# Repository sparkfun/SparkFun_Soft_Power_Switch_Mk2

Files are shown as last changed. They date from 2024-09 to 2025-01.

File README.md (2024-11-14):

SparkFun Soft Power Switch - JST 2mm
===================================================

SparkFun Soft Power Switch - JST 2mm (PRT-26993) (https://www.sparkfun.com/products/26993)

[*SparkFun Soft Power Switch - JST 2mm (PRT-26993)*](https://www.sparkfun.com/products/26993)

The Soft Power Switch - JST 2mm is a passive, hard on/off switch with software feedback and control. In other words, it's like the on/off switch on a laptop. A simple press will turn the system on. Another press can (with MCU intervention) turn off the system. And if things go really wrong, pressing and holding the button for ~7 seconds will force a power-down. If you're building something with an enclosed battery and need a good power button, this is the board you need.

The [Mk1 Soft Power Switch](https://www.sparkfun.com/products/17870) is great, but we do see occasional issues caused by component tolerances or the operating temperature. Mk2 is based on an application note by Texas Instruments, and is a completely digital design. It is based around a 74LVC1G175 D-type flip-flop - remember those?! - and is insensitive to temperature and component variation. It also includes improvements like: an over-current self-resetting 2A fuse; input and output LEDs. This version has JST 2mm battery connectors.

The PUSH pin can act as an output to a microcontroller indicating the state of the power button (high = not pressed, low = user is pressing power button). This can be used as an input to your firmware to begin to shut down before power is lost. PUSH is an open-drain output and requires a pull-up. Alternatively, the OFF pin can be driven **high** by the system forcing fast power off via software. (For Mk1, the Fast Off pin was driven **low**.)

The most common use case is something like this:

* Microcontroller begins running code and checks to see if the power button is still being pressed for X milliseconds.
* If not, it's just a tap, go back to sleep.
* If yes, power up and run normal program.

Later...

* User presses power button in normal program
* If power button is pressed for <X milliseconds, it's just a tap, ignore.
* If power button is pressed for >X milliseconds, it's time to power down.

The wake-up and power-down times can be tweaked for your own user experience but we found 500ms for power up and 2s for power down work really well.

If needed, pads are provided for a larger, external button.

The Soft Power Switch supports battery charging. If the target device has onboard LiPo charging, current can be passed back through the switch circuit and charge the battery.

<b>Heads up!</b> The Soft Power Switch - JST 2mm works up to 5.5V only. (Mk1 is good up to 12V.)

Pros:

* Very low µA quiescent current
* Hard override power down in case your microcontroller loses its mind
* PUSH and OFF pins can be connected to a microcontroller
* Supports battery charging

Cons:

* Limited to 2A continuous, 4A peak (fuse protected)
* No AC loads

Features
-------------------
* Input voltage: 5.5V maximum, 1.8V minimum
    * Typically ~3.7V from a single cell LiPo Battery
* Maximum current draw: 2A continuous, 4A peak (fuse protected)
* SIL2308 N&P-Channel MOSFET
    * 70mΩ (0.070 Ohm) typical P-Channel on-resistance
* Very low quiescent current: <1µA @ 3.75V, with VIN LED disabled
* 2x 2-Pin JST Right-Angle Connectors
    * VIN
    * VOUT
* Supports battery charging
* Built-in momentary push button
  * Hard override: push and hold the button for ~10 seconds
* Breakout PTH:
  * GND, VIN, VOUT
  * BTN: if desired, connect an external button between BTN and GND
  * PUSH: open-drain output, requires pull-up, low indicates button is pushed
  * OFF: drive high to turn the output off
* LEDs: VIN and VOUT (can be disabled if desired)
* Jumpers
  * Input power LED
  * Output power LED
* Dimensions: 1.0in. x 1.0in. (25.4mm x 25.4mm)
* Weight: 3.10g

Repository Contents
-------------------

* **.github/workflows** - YAML files used for GitHub Actions and GitHub Pages/mkdocs
* **/Examples** - Example sketches demonstrating how to read and control the switch
* **/Hardware** - KiCad design files (kicad_pro, .kicad_pcb, .kicad_sch)
  * **/Production** - Production panel files
* **/docs** - Online documentation files
  * **/assets** - Folder containing all the file assets used for product documentation
    *  **/3d_model** - Exported 3D models from KiCad
    * **/board_files** - Copy of design files used for product documentation
    * **/component_documentation** - Datasheets and manuals for hardware components
    * **/img** - Images for product documentation
  * **/github** - Files stating how to contribute and filing issues used for product documentation
  * **/javascript** - Folder containing custom javascript used for product documentation
  * **/stylesheet** - Folder containing CSS files used for product documentation
* **/overrides** - Customization files used for product documentation
  * **/.icons** - Icons used for GitHub used for product documentation
  * **./partials** - Used for product documentation
* **LICENSE.md** contains the license information

Documentation
--------------
* **[Hookup Guide](https://docs.sparkfun.com/SparkFun_Soft_Power_Switch_Mk2)** - Basic hookup guide for the Soft Power Switch - JST 2mm.

Product Versions
----------------
* [PRT-26993](https://www.sparkfun.com/products/26993) - SparkFun Red Release Soft Power Switch - JST 2mm
* [SPX-25365](https://www.sparkfun.com/products/25365) - Original SparkX Release Soft Power Switch Mk2 - JST 2mm
* [SPX-17870](https://www.sparkfun.com/products/17870) - Original SparkX Release Mk1

Version History
---------------
* v1.0 - SparkFun Soft Power Switch - JST 2mm (PRT-26993)
* v01 - Original SparkX Soft Power Switch MK2 - JST 2mm (SPX-25365)
* v1.0 - Original SparkX Soft Power Switch Mk1 (SPX-17870)

License Information
-------------------

This product is _**open source**_!

Please review the LICENSE.md file for license information.

If you have any questions or concerns on licensing, please contact technical support on our [SparkFun forums](https://forum.sparkfun.com/viewforum.php?f=123).

Distributed as-is; no warranty is given.

- Your friends at SparkFun.

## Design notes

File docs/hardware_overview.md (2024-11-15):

In this section, we will highlight the hardware and pins that are broken out on the SparkFun Soft Power Switch - JST 2mm. For more information, check out our [Resources and Going Further](../resources/) on the components used on the breakout board.

<div style="text-align: center;">
  <table>
    <tr style="vertical-align:middle;">
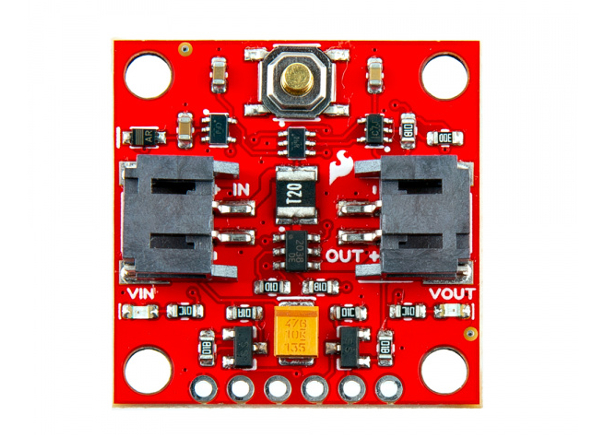
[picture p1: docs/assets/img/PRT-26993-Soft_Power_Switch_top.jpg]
Top View
     <td style="text-align: center; vertical-align: middle; border: solid 1px #cccccc;"></td>
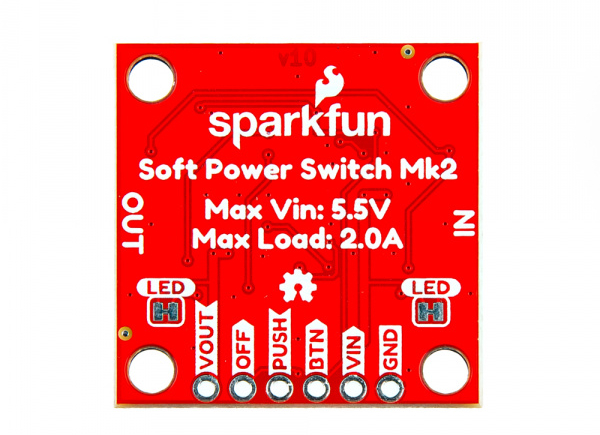
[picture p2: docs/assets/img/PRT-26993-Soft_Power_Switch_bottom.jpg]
Bottom View
     <td style="text-align: center; vertical-align: middle; border: solid 1px #cccccc;"></td>
    </tr>
    <tr style="vertical-align:middle;">
     <td style="text-align: center; vertical-align: middle; border: solid 1px #cccccc;"><i>Top View</i></td>
     <td style="text-align: center; vertical-align: middle; border: solid 1px #cccccc;"><i>Bottom View</i></td>
    </tr>
  </table>
</div>

### Soft Power Switch Versions

The [SparkX Mk1 Soft Power Switch](https://www.sparkfun.com/products/17870) is great, but we do see occasional issues caused by component tolerances or the operating temperature. Mk2 is based on an application note by Texas Instruments, and is a completely digital design. It is based around a 74LVC1G175 D-type flip-flop - remember those?! - and is insensitive to temperature and component variation.

<div style="text-align: center;">
  <table>
    <tr style="vertical-align:middle;">
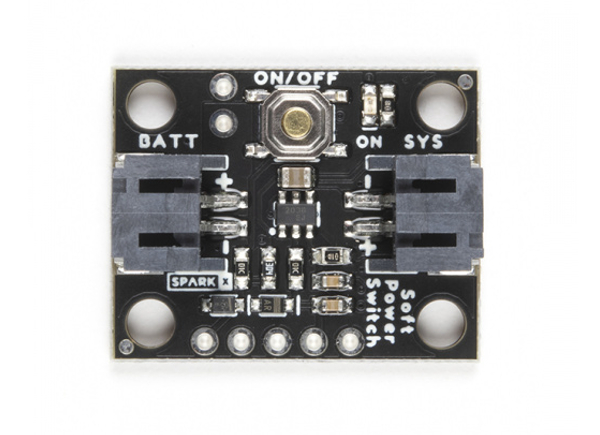
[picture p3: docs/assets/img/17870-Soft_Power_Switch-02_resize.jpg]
SparkX Soft Power Switch Mk1
     <td style="text-align: center; vertical-align: middle; border: solid 1px #cccccc;"></td>
     <td style="text-align: center; vertical-align: middle; border: solid 1px #cccccc;"><a href="../assets/img/PRT-26993-Soft_Power_Switch_top.jpg">SparkFun Soft Power Switch - JST 2mm</a></td>
    </tr>
    <tr style="vertical-align:middle;">
     <td style="text-align: center; vertical-align: middle; border: solid 1px #cccccc;"><i>SparkX Soft Power Switch Mk1</i></td>
     <td style="text-align: center; vertical-align: middle; border: solid 1px #cccccc;"><i>SparkFun Soft Power Switch - JST 2mm</i></td>
    </tr>
  </table>
</div>

It also includes improvements like:

- An over-current self-resetting 2A fuse.
- Input and output LEDs.
- LED jumpers.
- Improved momentary button (i.e. the height of the button is increased).

Differences include:

- The Soft Power Switch - JST 2mm works up to 5.5V only (the Mk1 is good up to 12V).
- For Mk2, driving the fast OFF pin HIGH by the system will force fast power off via software. However for Mk1, the fast OFF pin was driven low.
- Slightly bigger PCB: 1.0"x1.0" sized breakout (the Mk1 was 0.8"x1.0").

### Power

!!! warning
    The Soft Power Switch - JST 2mm works up to 5.5V only. (Mk1 is good up to 12V.)

!!! warning
    The Soft Power Switch - JST 2mm was designed to work with DC loads. Unfortunately, the board is not designed for AC loads.

!!! note
    Once the Soft Power Switch - JST 2mm is powered, it will take a few seconds to discharge power after disconnecting the power source from the IN port. So if you decide to do quick power cycle, the board can still be powered if there is not a long enough delay.

The maximum input voltage that the Soft Power Switch - JST 2mm can handle is **5.5V** while the minimum input voltage is _1.8V_. The board was designed to be used with single cell LiPo batteries with the built-in 2-pin JST connector, so the typical voltage will be about 3.7V nominally. The maximum current draw that the board can handle is 2A continuous and 4A peak (fuse protected). With the VIN LED disabled, the board has a very low quiescent current: <1&micro;A @ 3.75V.

* **VIN** &mdash; This pin is the voltage input. As stated above, the maximum input voltage is 5.5V while the minimum is 1.8V. Voltage is applied to this pin from a single cell LiPo battery which is about 3.7V nominally.
* **VOUT** &mdash; The output voltage of the board whenever the switch is active.
* **GND** &mdash; Of course, is the common, ground voltage (0V reference) for the system.

<div style="text-align: center;">
  <table>
    <tr style="vertical-align:middle;">
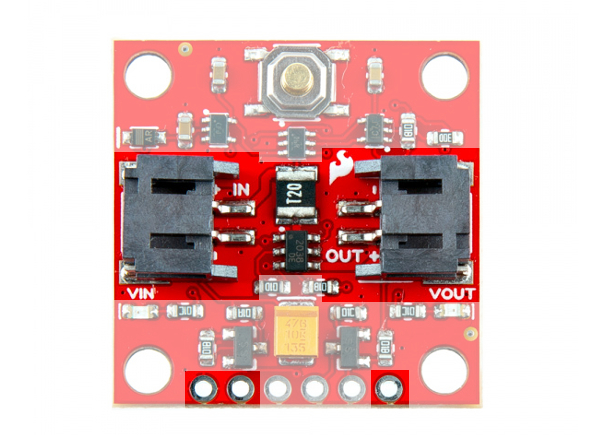
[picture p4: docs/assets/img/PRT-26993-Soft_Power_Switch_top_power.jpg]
Power, Ground and JST Connectors, Top View
     <td style="text-align: center; vertical-align: middle; border: solid 1px #cccccc;"></td>
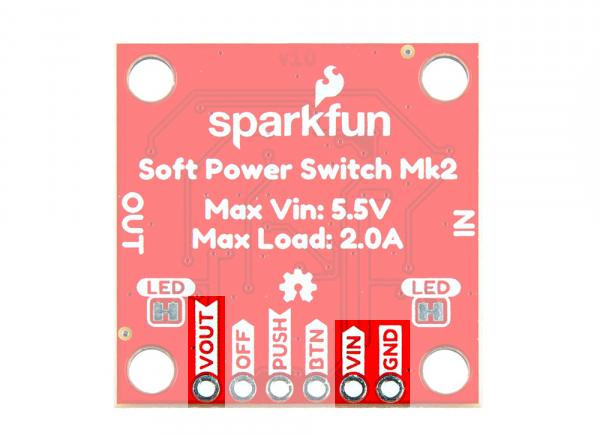
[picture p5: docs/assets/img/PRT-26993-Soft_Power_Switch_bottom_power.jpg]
Power, Ground and JST Connectors Highlighted, Bottom View
     <td style="text-align: center; vertical-align: middle; border: solid 1px #cccccc;"></td>
    </tr>
    <tr style="vertical-align:middle;">
     <td style="text-align: center; vertical-align: middle; border: solid 1px #cccccc;" colspan="2"><i>Power, Ground and JST Connectors Highlighted</i></td>
    </tr>
  </table>
</div>

The Soft Power Switch - JST 2mm also supports battery charging. If the target device has onboard LiPo charging, current can be passed back through the switch circuit and charge the battery.

### Power Button and Button State

The board includes a built-in momentary push button as the power button. This pin is broken out to a PTH for users to connect an external button. There is also the PUSH pin to indicate the button's state. The PUSH pin can act as an output to a microcontroller indicating the state of the power button (HIGH = not pressed, LOW = user is pressing power button). This can be used as an input to your firmware to begin to shut down before power is lost. Alternatively, there is also an OFF pin that can be driven HIGH by the system forcing fast power off via software. Below is a summary of the pins broken out.

* **BTN** &mdash; Short for button. If desired, connect this input pin to an external button between BTN and GND.
* **PUSH** &mdash; Open-drain output. This pin requires a pull-up resistor. A low indicates the button is pushed.
* **OFF** &mdash; Drive HIGH to turn the output off.

<div style="text-align: center;">
  <table>
    <tr style="vertical-align:middle;">
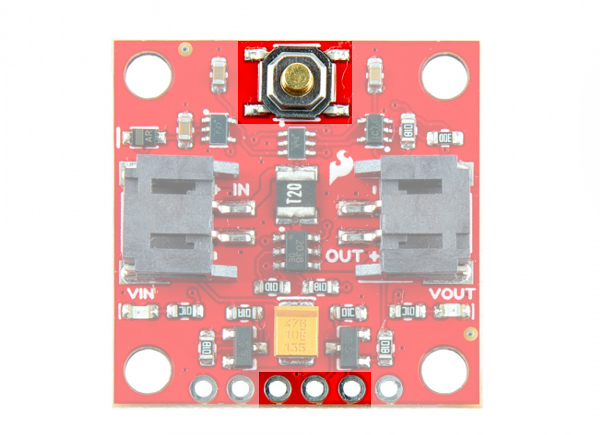
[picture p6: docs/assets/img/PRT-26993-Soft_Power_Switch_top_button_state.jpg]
Button Highlighted, Top View
     <td style="text-align: center; vertical-align: middle; border: solid 1px #cccccc;"></td>
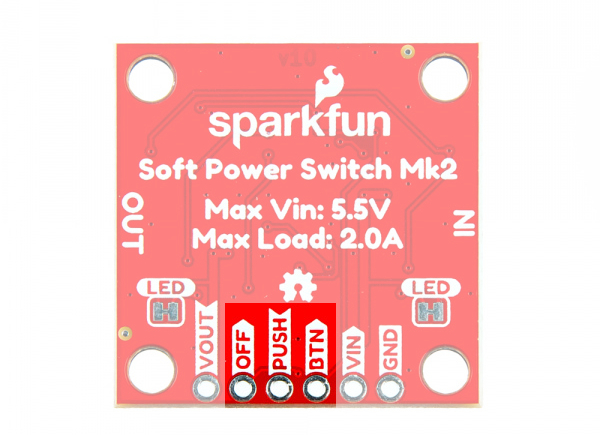
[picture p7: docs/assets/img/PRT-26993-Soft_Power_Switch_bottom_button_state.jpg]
Button PTH Highlighted, Bottom View
     <td style="text-align: center; vertical-align: middle; border: solid 1px #cccccc;"></td>
    </tr>
    <tr style="vertical-align:middle;">
     <td style="text-align: center; vertical-align: middle; border: solid 1px #cccccc;"><i>Top View</i></td>
     <td style="text-align: center; vertical-align: middle; border: solid 1px #cccccc;"><i>Bottom View</i></td>
    </tr>
  </table>
</div>

!!! note
    For Mk2, driving the fast OFF pin HIGH by the system will force fast power off via software. However for Mk1, the fast OFF pin was driven low.

### LEDs

* **VIN** &mdash; The VIN LED connects to the input voltage. This indicates when there is voltage at VIN. This LED can be disabled with the LED jumper on the back of the board and below the silkscreen labeled IN.
* **VOUT** &mdash; The VOUT LED connects to the output voltage. This indicates when there is voltage at VOUT. This LED can be disabled with the LED jumper on the back of the board and below the silkscreen labeled OUT.

<div style="text-align: center;">
  <table>
    <tr style="vertical-align:middle;">
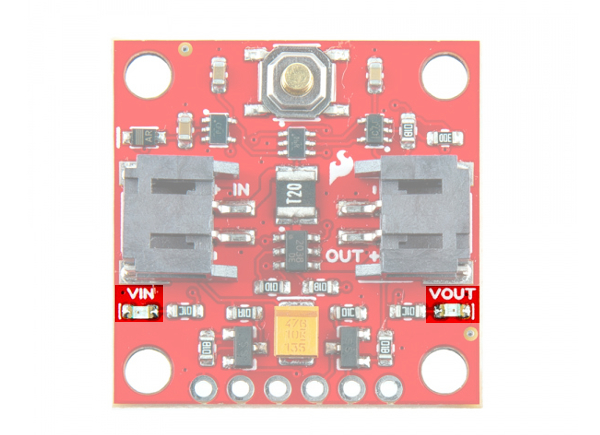
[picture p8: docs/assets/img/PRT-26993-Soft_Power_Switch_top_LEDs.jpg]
LEDs Highlighted
     <td style="text-align: center; vertical-align: middle; border: solid 1px #cccccc;"></td>
    </tr>
    <tr style="vertical-align:middle;">
     <td style="text-align: center; vertical-align: middle; border: solid 1px #cccccc;"><i>LEDs Highlighted</i></td>
    </tr>
  </table>
</div>

### Jumpers

!!!note
    If this is your first time working with jumpers, check out the [How to Work with Jumper Pads and PCB Traces](https://learn.sparkfun.com/tutorials/how-to-work-with-jumper-pads-and-pcb-traces/all) tutorial for more information.

The back of the board includes jumpers to configure the board.

* **LED** (below IN) &mdash; By default, the LED jumper located below the silkscreen labeled IN is closed. This connects the VIN LED to the input voltage. Cutting this will disable the LED for the input voltage.
* **LED** (below OUT) &mdash; By default, the LED jumper located below the silkscreen labeled OUT is closed. This connects the LED to the output voltage. Cutting this jumper will disable the LED for the output voltage.

<div style="text-align: center;">
  <table>
    <tr style="vertical-align:middle;">
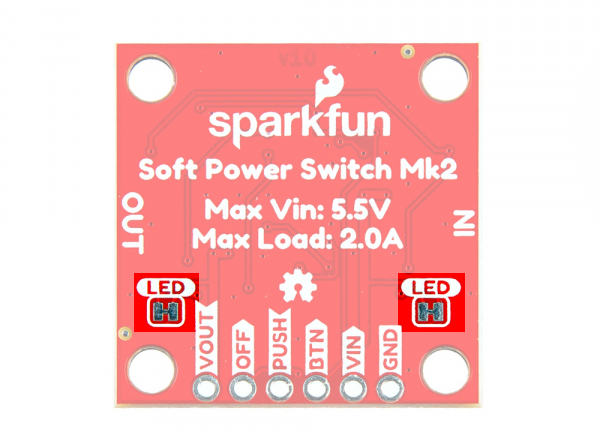
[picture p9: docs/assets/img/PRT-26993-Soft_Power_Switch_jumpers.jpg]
Jumpers Highlighted
     <td style="text-align: center; vertical-align: middle; border: solid 1px #cccccc;"></td>
    </tr>
    <tr style="vertical-align:middle;">
     <td style="text-align: center; vertical-align: middle; border: solid 1px #cccccc;"><i>Jumpers Highlighted</i></td>
    </tr>
  </table>
</div>

### 3D Model

A 3D model of the board and components was exported to a STEP file using KiCad.

<!-- Import the component -->
<script type="module" src="https://ajax.googleapis.com/ajax/libs/model-viewer/3.5.0/model-viewer.min.js"></script>

<div style="text-align: center;">
    <model-viewer src="../assets/3d_model/Soft_Power_Switch_JST_2mm_3D_Model.glb" camera-controls poster="../assets/3d_model/Soft_Power_Switch_JST_2mm_3D_image.png" environment-image="legacy" shadow-intensity="1.58" exposure="0.64" shadow-softness="0.24" tone-mapping="neutral" camera-orbit="-46.67deg 57.14deg 153.3m" field-of-view="30deg" style="width: 750px; height: 500px;">
    </model-viewer>
</div>
<br />
<div style="text-align: center">
    <a href="../assets/3d_model/Soft_Power_Switch_JST_2mm_3D_Model.step" target="stp_file" class="md-button">Click Here for the STEP File</a>
</div>

### Board Dimensions

The board is 1.0" x 1.0" (2.54mm x 2.54mm). There are 4x mounting holes by the corners of the board. You can use 4-40 standoffs to mount the board to a panel or enclosure.

<div style="text-align: center;">
  <table>
    <tr style="vertical-align:middle;">
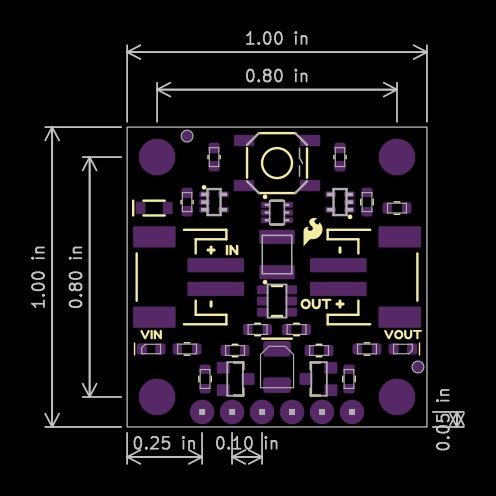
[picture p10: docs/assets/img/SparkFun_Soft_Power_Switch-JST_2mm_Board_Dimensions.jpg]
Board Dimensions
     <td style="text-align: center; vertical-align: middle; border: solid 1px #cccccc;"></td>
    </tr>
    <tr style="vertical-align:middle;">
     <td style="text-align: center; vertical-align: middle; border: solid 1px #cccccc;"><i>Board Dimensions</i></td>
    </tr>
  </table>
</div>

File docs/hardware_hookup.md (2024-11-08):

In this section, we will go over how to connect to the Soft Power Switch - JST 2mm.

### Connecting via PTH

For temporary connections to the PTHs, you could use IC hooks to test out the pins. However, you'll need to solder headers or wires of your choice to the board for a secure connection. You can choose between a combination of [header pins and jumper wires](https://learn.sparkfun.com/tutorials/how-to-solder-through-hole-soldering/all), or [stripping wire and soldering the wire](https://learn.sparkfun.com/tutorials/working-with-wire/all) directly to the board.

<div class="grid cards col-2" markdown>

-   <a href="https://learn.sparkfun.com/tutorials/how-to-solder-through-hole-soldering/all">
      <figure markdown>
        How to Solder: Through Hole Soldering
      </figure>
    </a>

    ---

    <a href="https://learn.sparkfun.com/tutorials/how-to-solder-through-hole-soldering/all">
      <b>How to Solder: Through Hole Soldering</b>
    </a>
<!-- ----------WHITE SPACE BETWEEN GRID CARDS---------- -->

-   <a href="https://learn.sparkfun.com/tutorials/working-with-wire/all">
      <figure markdown>
        Working with Wire
      </figure>
    </a>

    ---

    <a href="https://learn.sparkfun.com/tutorials/working-with-wire/all">
      <b>Working with Wire</b>
    </a>
<!-- ----------WHITE SPACE BETWEEN GRID CARDS---------- -->
</div>

### Input Power

The board was designed to be used with single cell LiPo batteries with the built-in 2-pin JST connector. Simply insert the LiPo Battery into the JST connector labeled as IN.

<div style="text-align: center;">
  <table>
    <tr style="vertical-align:middle;">
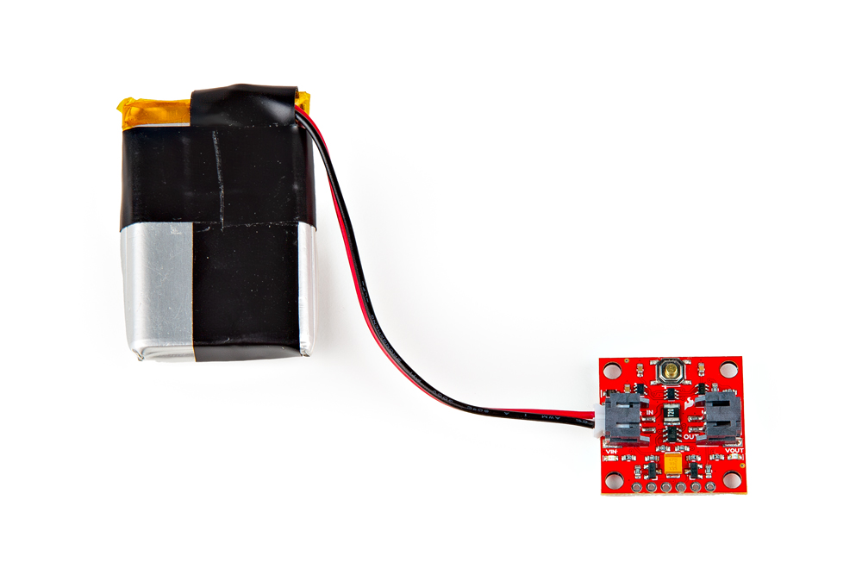
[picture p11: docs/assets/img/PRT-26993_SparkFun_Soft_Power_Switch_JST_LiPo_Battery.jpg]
LiPo Battery inserted into JST Connector
     <td style="text-align: center; vertical-align: middle; border: solid 1px #cccccc;"></td>
    </tr>
    <tr style="vertical-align:middle;">
     <td style="text-align: center; vertical-align: middle; border: solid 1px #cccccc;"><i>LiPo Battery inserted into JST Connector</i></td>
    </tr>
  </table>
</div>

Of course, power can also be soldered directly to the PTH as well.

<div style="text-align: center;">
    <table>
        <tr>
            <th style="text-align: center; vertical-align: middle; border: solid 1px #cccccc;">Power Supply
            </th>
            <th style="text-align: center; vertical-align: middle; border: solid 1px #cccccc;">Soft Power Switch - JST 2mm
            </th>
        </tr>
        <tr>
            <td style="text-align: center; border: solid 1px #cccccc;" bgcolor="#f2dede"><font color="#000000">1.8V to 5.5V<br /> Typically 3.7V <br />if using a LiPo Battery (Red Wire)</font>
            </td>
            <td style="text-align: center; border: solid 1px #cccccc;" bgcolor="#f2dede"><font color="#000000">VIN</font>
            </td>
        </tr>
        <tr>
            <td style="text-align: center; border: solid 1px #cccccc;" bgcolor="#DDDDDD"><font color="#000000">GND (Black Wire)</font>
            </td>
            <td style="text-align: center; border: solid 1px #cccccc;" bgcolor="#DDDDDD"><font color="#000000">GND</font>
            </td>
        </tr>
    </table>
</div>

Remember, the Soft Power Switch - JST 2mm also supports battery charging. If the target device has onboard LiPo charging, current can be passed back through the switch circuit and charge the battery. For more information about LiPo battery charging and care, make sure to check the tutorial on [Single Cell LiPo Battery Care](https://learn.sparkfun.com/tutorials/single-cell-lipo-battery-care).

<div class="grid cards" style="width:500px; margin: 0 auto;" markdown>

-   <a href="https://learn.sparkfun.com/tutorials/single-cell-lipo-battery-care">
      <figure markdown>
        Single Cell LiPo Battery Care
      </figure>
    </a>

    ---

    <a href="https://learn.sparkfun.com/tutorials/single-cell-lipo-battery-care">
      <b>Single Cell LiPo Battery Care</b>
    </a>
<!-- ----------WHITE SPACE BETWEEN GRID CARDS---------- -->
</div>

### Output Power

For boards that have a built-in 2-pin JST connector for LiPo batteries, you can [splice two](https://learn.sparkfun.com/tutorials/working-with-wire/all#how-to-splice-wires) JST cables together. Then you can insert it between the Soft Power Switch's JST connector labeled OUT and the other end will be inserted into the JST connector of the target board being powered (in this case, the SparkFun IoT RedBoard - ESP32 Development Board).

<div style="text-align: center;">
  <table>
    <tr style="vertical-align:middle;">
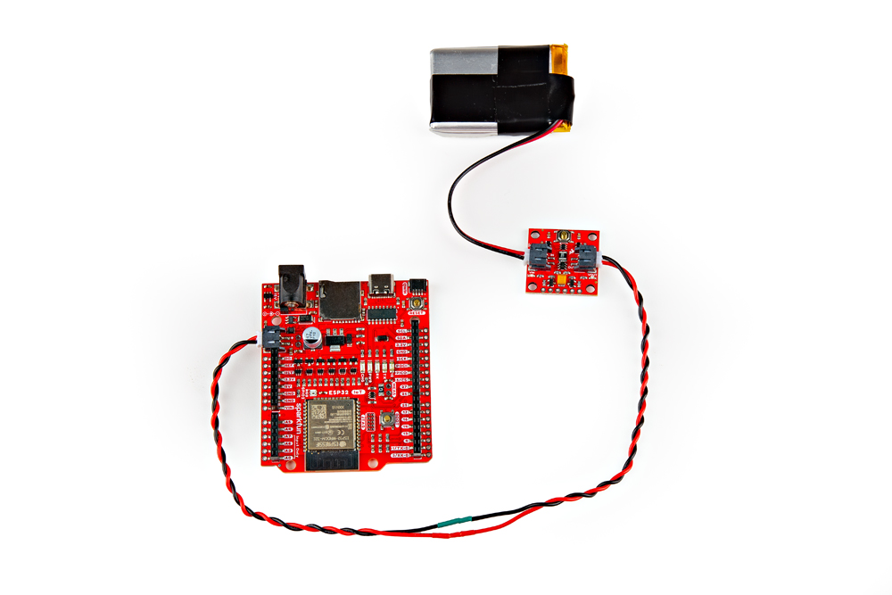
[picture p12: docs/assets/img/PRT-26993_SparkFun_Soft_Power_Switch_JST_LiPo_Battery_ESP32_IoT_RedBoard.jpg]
JST Cable between the Soft Power Switch - JST 2mm and IoT RedBoard - ESP32
     <td style="text-align: center; vertical-align: middle; border: solid 1px #cccccc;"></td>
    </tr>
    <tr style="vertical-align:middle;">
     <td style="text-align: center; vertical-align: middle; border: solid 1px #cccccc;"><i>JST Cable between the Soft Power Switch - JST 2mm and IoT RedBoard - ESP32</i></td>
    </tr>
  </table>
</div>

Of course, power can also be soldered directly to the PTH as well. Since we are powering the output with a single cell LiPo battery, you will need to connect it to your system's battery input. In this case, VBATT net was labeled as + on the board. Depending on your system, it may be labeled as VBAT, RAW, or VCC. Make sure to check the board's hardware design before deciding to connect VOUT to your system.

<div style="text-align: center;">
    <table>
        <tr>
            <th style="text-align: center; vertical-align: middle; border: solid 1px #cccccc;">Soft Power Switch - JST 2mm
            </th>
            <th style="text-align: center; vertical-align: middle; border: solid 1px #cccccc;">SparkFun IoT RedBoard -<br />ESP32 Development Board
            </th>
        </tr>
        <tr>
            <td style="text-align: center; border: solid 1px #cccccc;" bgcolor="#f2dede"><font color="#000000">VOUT</font>
            </td>
            <td style="text-align: center; border: solid 1px #cccccc;" bgcolor="#f2dede"><font color="#000000">+</font>
            </td>
        </tr>
        <tr>
            <td style="text-align: center; border: solid 1px #cccccc;" bgcolor="#DDDDDD"><font color="#000000">GND</font>
            </td>
            <td style="text-align: center; border: solid 1px #cccccc;" bgcolor="#DDDDDD"><font color="#000000">-</font>
            </td>
        </tr>
    </table>
</div>

!!! note
    The voltage range of the Soft Power Switch - JST 2mm is between 1.8V to 5.5V. Users can also connect a different power source and connect the output to VIN or 5V of their system. Just make that the voltage is within the operating range of the target device.

### External Button

For users that need to connect an external button, you will simply need to connect one terminal of the button to BTN and the other terminal to GND. In this case, IC hooks and F/M jumper wires were used to connect an external momentary push button.

<div style="text-align: center;">
  <table>
    <tr style="vertical-align:middle;">
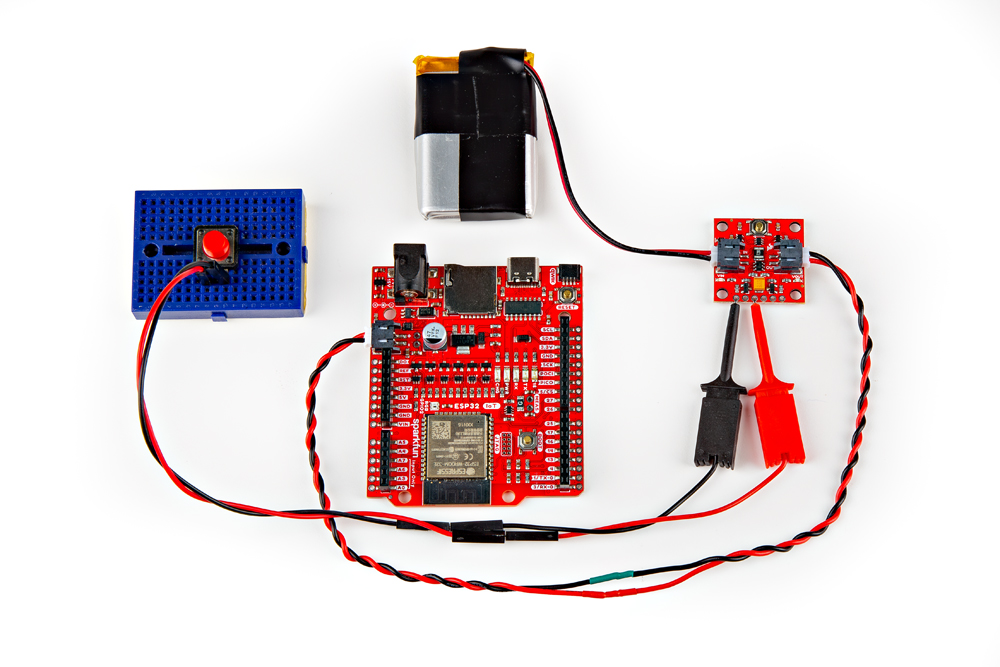
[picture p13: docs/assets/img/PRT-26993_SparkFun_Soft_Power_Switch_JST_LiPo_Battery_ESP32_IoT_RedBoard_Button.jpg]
External Button Connected
     <td style="text-align: center; vertical-align: middle; border: solid 1px #cccccc;"></td>
    </tr>
    <tr style="vertical-align:middle;">
     <td style="text-align: center; vertical-align: middle; border: solid 1px #cccccc;"><i>External Button Connected</i></td>
    </tr>
  </table>
</div>

<div style="text-align: center;">
    <table>
        <tr>
            <th style="text-align: center; vertical-align: middle; border: solid 1px #cccccc;">Soft Power Switch - JST 2mm
            </th>
            <th style="text-align: center; vertical-align: middle; border: solid 1px #cccccc;">Button
            </th>
        </tr>
        <tr>
            <td style="text-align: center; border: solid 1px #cccccc;" bgcolor="#cce5ff"><font color="#000000">BTN</font>
            </td>
            <td style="text-align: center; border: solid 1px #cccccc;" bgcolor="#cce5ff"><font color="#000000">Normally Open Pin</font>
            </td>
        </tr>
        <tr>
        <td style="text-align: center; border: solid 1px #cccccc;" bgcolor="#DDDDDD"><font color="#000000">GND</font>
        </td>
            <td style="text-align: center; border: solid 1px #cccccc;" bgcolor="#DDDDDD"><font color="#000000">Common Pin</font>
            </td>
        </tr>
    </table>
</div>

### Off and Push

To connect to the OFF and PUSH pins with a microcontroller, you will need two GPIO pins with code to control or read the Soft Power Switch Mk2. Depending on your microcontroller, you may need to adjust the pin connections and definitions with respect to the microcontroller's GPIO pins.

<div style="text-align: center;">
  <table>
    <tr style="vertical-align:middle;">
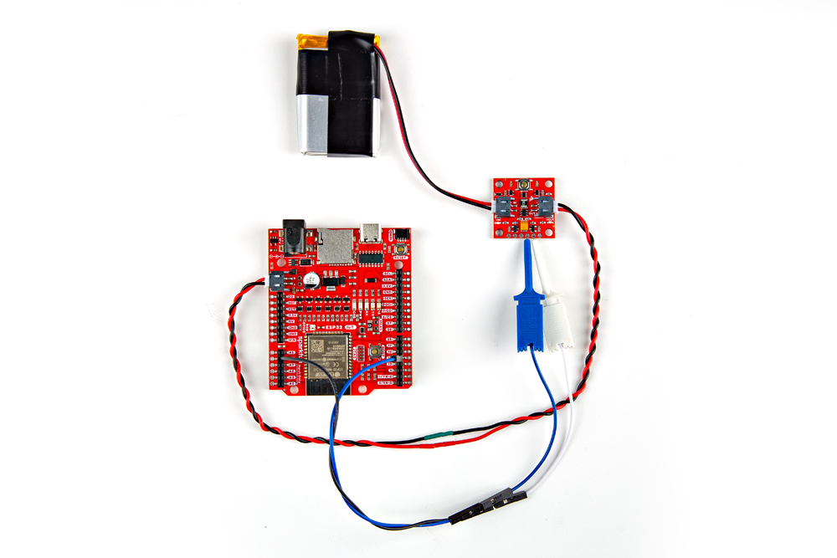
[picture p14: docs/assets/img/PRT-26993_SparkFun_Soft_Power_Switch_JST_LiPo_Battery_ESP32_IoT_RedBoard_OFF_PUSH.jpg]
OFF and PUSH Pins Connected to IoT RedBoard
     <td style="text-align: center; vertical-align: middle; border: solid 1px #cccccc;"></td>
    </tr>
    <tr style="vertical-align:middle;">
     <td style="text-align: center; vertical-align: middle; border: solid 1px #cccccc;"><i>OFF and PUSH Pins Connected to IoT RedBoard</i></td>
    </tr>
  </table>
</div>

<div style="text-align: center;">
    <table>
        <tr>
            <th style="text-align: center; vertical-align: middle; border: solid 1px #cccccc;">Soft Power Switch - JST 2mm
            </th>
            <th style="text-align: center; vertical-align: middle; border: solid 1px #cccccc;">SparkFun IoT RedBoard -<br />ESP32 Development Board
            </th>
        </tr>
        <tr>
            <td style="text-align: center; border: solid 1px #cccccc;" bgcolor="#cce5ff"><font color="#000000">OFF</font>
            </td>
            <td style="text-align: center; border: solid 1px #cccccc;" bgcolor="#cce5ff"><font color="#000000"><code>32</code> (or <code>A4</code>)</font>
            </td>
        </tr>
        <tr>
            <td style="text-align: center; border: solid 1px #cccccc;" bgcolor="#d4edda"><font color="#000000">PUSH</font>
            </td>
            <td style="text-align: center; border: solid 1px #cccccc;" bgcolor="#d4edda"><font color="#000000"><code>14</code></font>
            </td>
        </tr>
    </table>
</div>

!!! tip
    Remember, the PUSH pin requires a pull-up resistor when connecting it to a microcontroller's GPIO pin. You can use the [internal pull-up resistor](https://learn.sparkfun.com/tutorials/pull-up-resistors/all) on the microcontroller so that the pin is not floating.

### Arduino Serial Output

To view the Arduino's serial output when powering the system with a LiPo battery, you will need to wire a 3.3V Serial Basic Breakout to the Arduino&apos;s serial UART. In this case, we connected to the SparkFun IoT RedBoard - ESP32 Development Board primary UART port. Depending on your microcontroller, you may need to adjust the pin connections and definitions with respect to the microcontroller's UART pins.

<div style="text-align: center;">
    <table>
        <tr>
            <th style="text-align: center; vertical-align: middle; border: solid 1px #cccccc;">3.3V Serial Basic
            </th>
            <th style="text-align: center; vertical-align: middle; border: solid 1px #cccccc;">SparkFun IoT RedBoard<br />- ESP32 Development Board
            </th>
        </tr>
        <tr>
            <td style="text-align: center; border: solid 1px #cccccc;" bgcolor="#d4edda"><font color="#000000">TXO</font>
            </td>
            <td style="text-align: center; border: solid 1px #cccccc;" bgcolor="#d4edda"><font color="#000000">3/RX-0</font>
            </td>
        </tr>

        <tr>
            <td style="text-align: center; border: solid 1px #cccccc;" bgcolor="#ffdaaf"><font color="#000000">RXI</font>
            </td>
            <td style="text-align: center; border: solid 1px #cccccc;" bgcolor="#ffdaaf"><font color="#000000">1/TX-0</font>
            </td>
        </tr>
        <tr>
            <td style="text-align: center; border: solid 1px #cccccc;" bgcolor="#DDDDDD"><font color="#000000">GND</font>
            </td>
            <td style="text-align: center; border: solid 1px #cccccc;" bgcolor="#DDDDDD"><font color="#000000">GND</font>
            </td>
        </tr>
    </table>
</div>

<div style="text-align: center;">
  <table>
    <tr style="vertical-align:middle;">
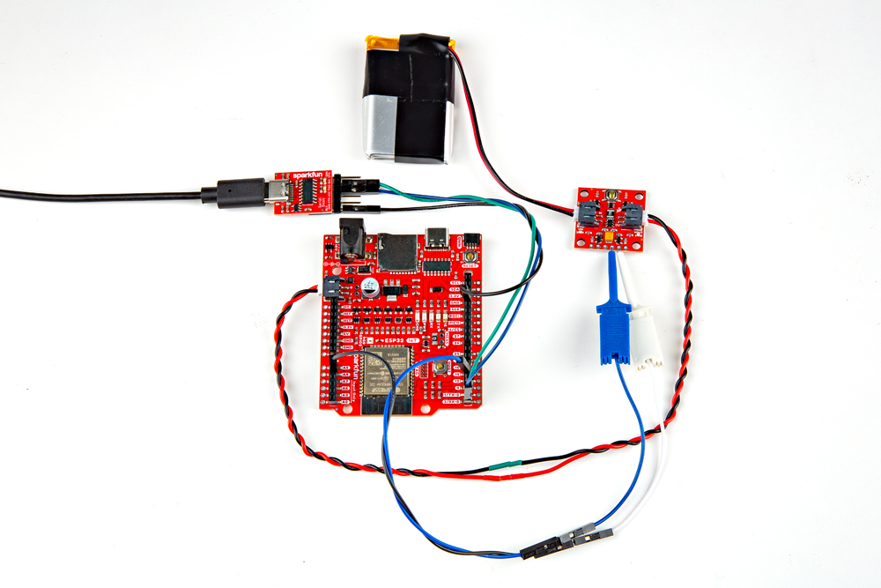
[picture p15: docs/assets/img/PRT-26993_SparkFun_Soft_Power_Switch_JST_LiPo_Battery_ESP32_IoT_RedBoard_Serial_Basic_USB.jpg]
3.3V Serial Basic Connected to ESP32 IoT RedBoard Hardware UART
     <td style="text-align: center; vertical-align: middle; border: solid 1px #cccccc;"></td>
    </tr>
    <tr style="vertical-align:middle;">
     <td style="text-align: center; vertical-align: middle; border: solid 1px #cccccc;"><i>3.3V Serial Basic Connected to ESP32 IoT RedBoard Hardware UART</i></td>
    </tr>
  </table>
</div>

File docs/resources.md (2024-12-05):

Now that you've successfully got your SparkFun Soft Power Switch Mk2 - JST 2mm up and running, it's time to incorporate it into your own project! For more information, check out the resources below:

* [Schematic (PDF)](../assets/board_files/Soft_Power_Switch_JST_2mm_Schematic_V10.pdf)
* [KiCad Files (ZIP)](../assets/board_files/Soft_Power_Switch-JST_2mm_V10.zip)
* [3D Model (STEP)](../assets/3d_model/Soft_Power_Switch_JST_2mm_3D_Model.step)
* [Board Dimensions (JPG)](../assets/img/SparkFun_Soft_Power_Switch-JST_2mm_Board_Dimensions.jpg)
* Component Datasheets
    * [SN74LVC1G14 (PDF)](../assets/component_documentation/sn74lvc1g14.pdf)
    * [SN74LVC1G17 (PDF)](../assets/component_documentation/sn74lvc1g17.pdf)
    * [SN74LVC1G175 (PDF)](../assets/component_documentation/sn74lvc1g175.pdf)
    * [Texas Instruments Application Report: Push-Button Circuit SCEA048B (PDF)](../assets/component_documentation/TI_Push_Button_scea048b.pdf)
* [GitHub Hardware Repo](https://github.com/sparkfun/SparkFun_Soft_Power_Switch_Mk2)

Or check out the other Soft Power Switch with USB connectors!

<div class="grid cards" style="width:500px; margin: 0 auto;" markdown>
<!-- ----------WHITE SPACE BETWEEN GRID CARDS---------- -->
-   <a href="https://docs.sparkfun.com/SparkFun_Soft_Power_Switch_USB-C">
      <figure markdown>
        SparkFun Soft Power Switch - USB-C Hookup Guide
      </figure>
    </a>

    ---

    <a href="https://docs.sparkfun.com/SparkFun_Soft_Power_Switch_USB-C">
      <b>SparkFun Soft Power Switch - USB-C Hookup Guide</b>
    </a>
<!-- ----------WHITE SPACE BETWEEN GRID CARDS---------- -->
</div>

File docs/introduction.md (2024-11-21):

The [SparkFun Soft Power Switch](https://www.sparkfun.com/products/26993) is a passive, hard on/off switch with software feedback and control. In other words, it's like the on/off switch on a laptop. A simple press will turn the system on. Another press can (with MCU intervention) turn off the system. And if things go really wrong, pressing and holding the button for ~10 seconds will force a power-down. If you're building something with an enclosed battery and need a good power button, this is the board you need. This version has JST 2mm battery connectors but we also have a version with [USB-C](https://www.sparkfun.com/products/27081) connectors.

<div class="grid cards" style="width:500px; margin: 0 auto;" markdown>

-   <a href="https://www.sparkfun.com/products/26993">
      <figure markdown>
        SparkFun Soft Power Switch - JST 2mm
      </figure>
    </a>

    ---

    <a href="https://www.sparkfun.com/products/26993">
      <b>SparkFun Soft Power Switch - JST 2mm</b>
      <br />
      PRT-26993
      <br />
      <center>[Purchase from SparkFun :fontawesome-solid-cart-plus:](https://www.sparkfun.com/products/26993){ .md-button .md-button--primary }</center>
    </a>
</div>

In this tutorial, we'll go over the hardware and how to hookup the SparkFun Soft Power Switch - JST 2mm to an Arduino. We will also go over an Arduino example to get started.

### Required Materials

To follow along with this tutorial, you will need the following materials. You may not need everything though depending on what you have. Add it to your cart, read through the guide, and adjust the cart as necessary.

<div class="grid cards col-4" markdown>

<!-- ----------WHITE SPACE BETWEEN PRODUCTS---------- -->
-   <a href="https://www.sparkfun.com/products/15424">
      <figure markdown>
        Reversible USB A to C Cable - 2m
      </figure>
    </a>

    ---

    <a href="https://www.sparkfun.com/products/15424">
      <b>Reversible USB A to C Cable - 2m</b>
      <br />
      CAB-15424
    </a>
<!-- ----------WHITE SPACE BETWEEN PRODUCTS---------- -->
-   <a href="https://www.sparkfun.com/products/19177">
      <figure markdown>
        SparkFun IoT RedBoard - ESP32 Development Board
      </figure>
    </a>

    ---

    <a href="https://www.sparkfun.com/products/19177">
      <b>SparkFun IoT RedBoard - ESP32 Development Board</b>
      <br />
      WRL-19177
    </a>
<!-- ----------WHITE SPACE BETWEEN PRODUCTS---------- -->
-   <a href="https://www.sparkfun.com/products/26993">
      <figure markdown>
        SparkFun Soft Power Switch - JST 2mm
      </figure>
    </a>

    ---

    <a href="https://www.sparkfun.com/products/26993">
      <b>SparkFun Soft Power Switch - JST 2mm</b>
      <br />
      PRT-26993
    </a>
<!-- ----------WHITE SPACE BETWEEN PRODUCTS---------- -->
-   <a href="https://www.sparkfun.com/products/18286">
      <figure markdown>
        Lithium Ion Battery - 1250mAh (IEC62133 Certified)
      </figure>
    </a>

    ---

    <a href="https://www.sparkfun.com/products/18286">
      <b>Lithium Ion Battery - 1250mAh (IEC62133 Certified)</b>
      <br />
      PRT-18286
    </a>
<!-- ----------WHITE SPACE BETWEEN PRODUCTS---------- -->
-   <a href="https://www.sparkfun.com/products/9914">
      <figure markdown>
        JST Jumper 2 Wire Assembly
      </figure>
    </a>

    ---

    <a href="https://www.sparkfun.com/products/9914">
      <b>JST Jumper 2 Wire Assembly</b>
      <br>
      PRT-09914
    </a>
<!-- ----------WHITE SPACE BETWEEN PRODUCTS---------- -->
-   <a href="https://www.sparkfun.com/products/9741">
      <figure markdown>
        IC Hook with Pigtail
      </figure>
    </a>

    ---

    <a href="https://www.sparkfun.com/products/9741">
      <b>IC Hook with Pigtail</b>
      <br>
      CAB-09741
    </a>
<!-- ----------WHITE SPACE BETWEEN PRODUCTS---------- -->
-   <a href="https://www.sparkfun.com/products/14460">
      <figure markdown>
        Multicolor Buttons - 4-pack
      </figure>
    </a>

    ---

    <a href="https://www.sparkfun.com/products/14460">
      <b>Multicolor Buttons - 4-pack</b>
      <br />
      PRT-14460
    </a>
<!-- ----------WHITE SPACE BETWEEN PRODUCTS---------- -->
-   <a href="https://www.sparkfun.com/products/15096">
      <figure markdown>
        SparkFun Serial Basic Breakout - CH340C and USB-C
      </figure>
    </a>

    ---

    <a href="https://www.sparkfun.com/products/15096">
      <b>SparkFun Serial Basic Breakout - CH340C and USB-C</b>
      <br />
      DEV-15096
    </a>
<!-- ----------WHITE SPACE BETWEEN PRODUCTS---------- -->
-   <a href="https://www.sparkfun.com/products/12045">
      <figure markdown>
        Breadboard - Mini Modular (Blue)
      </figure>
    </a>

    ---

    <a href="https://www.sparkfun.com/products/12045">
      <b>Breadboard - Mini Modular (Blue)</b>
      <br />
      PRT-12045
    </a>
<!-- ----------WHITE SPACE BETWEEN PRODUCTS---------- -->
-   <a href="https://www.sparkfun.com/products/9140">
      <figure markdown>
        Jumper Wires Premium 6
      <br />
      PRT-09140
    </a>
<!-- ----------WHITE SPACE BETWEEN PRODUCTS---------- -->
-   <a href="https://www.sparkfun.com/products/8431">
      <figure markdown>
        Jumper Wires Premium 6
      <br />
      PRT-08431
    </a>
<!-- ----------WHITE SPACE BETWEEN PRODUCTS---------- -->
</div>

### 2-Pin JST Cables

For those that want to take advantage of the 2-pin JST-style connector with 2mm pitch, you can grab the following cables from the catalog. Two jumper 2 wire assemblies were spliced together with heat shrink to easily connect the Soft Power Switch - JST 2mm to the IoT RedBoard's 2-pin JST-style connector.

<div class="grid cards col-4" markdown>
<!-- ----------WHITE SPACE BETWEEN PRODUCTS---------- -->
-   <a href="https://www.sparkfun.com/products/8670">
      <figure markdown>
        Jumper Wire - JST Black Red
      </figure>
    </a>

    ---

    <a href="https://www.sparkfun.com/products/8670">
      <b>Jumper Wire - JST Black Red</b>
      <br />
      PRT-08670
    </a>
<!-- ----------WHITE SPACE BETWEEN PRODUCTS---------- -->
-   <a href="https://www.sparkfun.com/products/9914">
      <figure markdown>
        JST Jumper 2 Wire Assembly
      </figure>
    </a>

    ---

    <a href="https://www.sparkfun.com/products/9914">
      <b>JST Jumper 2 Wire Assembly</b>
      <br>
      PRT-09914
    </a>
<!-- ----------WHITE SPACE BETWEEN PRODUCTS---------- -->
-   <a href="https://www.sparkfun.com/products/8671">
      <figure markdown>
        Jumper Wire - JST Black Blue
      </figure>
    </a>

    ---

    <a href="https://www.sparkfun.com/products/8671">
      <b>Jumper Wire - JST Black Blue</b>
      <br>
      PRT-08671
    </a>
<!-- ----------WHITE SPACE BETWEEN PRODUCTS---------- -->

</div>

### Tools

For users connecting to the plated through holes, you will need a soldering iron, solder, and [general soldering accessories](https://www.sparkfun.com/categories/49).

<div class="grid cards col-4" markdown>

-   <a href="https://www.sparkfun.com/products/24063">
      <figure markdown>
        PINECIL Soldering Iron Kit
      </figure>
    </a>

    ---

    <a href="https://www.sparkfun.com/products/24063">
      <b>PINECIL Soldering Iron Kit</b>
      <br />
      TOL-24063
    </a>
<!-- ----------WHITE SPACE BETWEEN PRODUCTS---------- -->
-   <a href="https://www.sparkfun.com/products/9163">
      <figure markdown>
        Solder Lead Free - 15-gram Tube
      </figure>
    </a>

    ---

    <a href="https://www.sparkfun.com/products/9163">
      <b>Solder Lead Free - 15-gram Tube</b>
      <br>
      TOL-09163
    </a>
<!-- ----------WHITE SPACE BETWEEN PRODUCTS---------- -->
-   <a href="https://www.sparkfun.com/products/11375">
      <figure markdown>
        Hook-Up Wire - Assortment (Stranded, 22 AWG)
      </figure>
    </a>

    ---

    <a href="https://www.sparkfun.com/products/11375">
      <b>Hook-Up Wire - Assortment (Stranded, 22 AWG)</b>
      <br />
      PRT-11375
    </a>
<!-- ----------WHITE SPACE BETWEEN PRODUCTS---------- -->
-   <a href="https://www.sparkfun.com/products/12630">
      <figure markdown>
        Wire Strippers - 30AWG (Hakko)
      </figure>
    </a>

    ---

    <a href="https://www.sparkfun.com/products/12630">
      <b>Wire Strippers - 30AWG (Hakko)</b>
      <br />
      TOL-12630
    </a>
<!-- ----------WHITE SPACE BETWEEN PRODUCTS---------- -->
-   <a href="https://www.sparkfun.com/products/11952">
      <figure markdown>
        Flush Cutters - Hakko
      </figure>
    </a>

    ---

    <a href="https://www.sparkfun.com/products/11952">
      <b>Flush Cutters - Hakko</b>
      <br />
      TOL-11952
    </a>
<!-- ----------WHITE SPACE BETWEEN PRODUCTS---------- -->

-   <a href="https://www.sparkfun.com/products/9353">
      <figure markdown>
        Heat Shrink Kit
      </figure>
    </a>

    ---

    <a href="https://www.sparkfun.com/products/9353">
      <b>Heat Shrink Kit</b>
      <br />
      PRT-09353
    </a>
<!-- ----------WHITE SPACE BETWEEN PRODUCTS---------- -->
</div>

### Prototyping Accessories

Depending on your setup, you may want to use IC hooks for a temporary connection. However, you will want to solder header pins to connect devices to the plated through holes for a secure connection.

<div class="grid cards col-4" markdown>
<!-- ----------WHITE SPACE BETWEEN PRODUCTS---------- -->
-   <a href="https://www.sparkfun.com/products/12002">
      <figure markdown>
        Breadboard - Self-Adhesive (White)
      </figure>
    </a>

    ---

    <a href="https://www.sparkfun.com/products/12002">
      <b>Breadboard - Self-Adhesive (White)</b>
      <br />
      PRT-12002
    </a>
<!-- ----------WHITE SPACE BETWEEN PRODUCTS---------- -->
-   <a href="https://www.sparkfun.com/products/9741">
      <figure markdown>
        IC Hook with Pigtail
      </figure>
    </a>

    ---

    <a href="https://www.sparkfun.com/products/9741">
      <b>IC Hook with Pigtail</b>
      <br>
      CAB-09741
    </a>
<!-- ----------WHITE SPACE BETWEEN PRODUCTS---------- -->
-   <a href="https://www.sparkfun.com/products/553">
      <figure markdown>
        Break Away Male Headers - Right Angle
      </figure>
    </a>

    ---

    <a href="https://www.sparkfun.com/products/553">
      <b>Break Away Male Headers - Right Angle</b>
      <br />
      PRT-00553
    </a>
<!-- ----------WHITE SPACE BETWEEN PRODUCTS---------- -->
-   <a href="https://www.sparkfun.com/products/9140">
      <figure markdown>
        Jumper Wires Premium 6
      <br />
      PRT-09140
    </a>
<!-- ----------WHITE SPACE BETWEEN PRODUCTS---------- -->
-   <a href="https://www.sparkfun.com/products/115">
      <figure markdown>
        Female Headers
      </figure>
    </a>

    ---

    <a href="https://www.sparkfun.com/products/115">
      <b>Female Headers</b>
      <br />
      PRT-00115
    </a>
<!-- ----------WHITE SPACE BETWEEN PRODUCTS---------- -->
-   <a href="https://www.sparkfun.com/products/8431">
      <figure markdown>
        Jumper Wires Premium 6
      <br />
      PRT-08431
    </a>
<!-- ----------WHITE SPACE BETWEEN PRODUCTS---------- -->
</div>

### Suggested Reading

If you aren’t familiar with the following concepts, we also recommend checking out a few of these tutorials before continuing.

<div class="grid cards col-4" markdown>
<!-- ----------WHITE SPACE BETWEEN GRID CARDS---------- -->
-   <a href="https://learn.sparkfun.com/tutorials/how-to-solder-through-hole-soldering">
      <figure markdown>
        How to Solder: Through-Hole Soldering
      </figure>
    </a>

    ---

    <a href="https://learn.sparkfun.com/tutorials/how-to-solder-through-hole-soldering">
      <b>How to Solder: Through-Hole Soldering</b>
    </a>
<!-- ----------WHITE SPACE BETWEEN GRID CARDS---------- -->
-   <a href="https://learn.sparkfun.com/tutorials/working-with-wire">
      <figure markdown>
        Working with Wire
      </figure>
    </a>

    ---

    <a href="https://learn.sparkfun.com/tutorials/working-with-wire">
      <b>Working with Wire</b>
    </a>
<!-- ----------WHITE SPACE BETWEEN GRID CARDS---------- -->
-   <a href="https://learn.sparkfun.com/tutorials/installing-arduino-ide">
      <figure markdown>
        Installing Arduino IDE
      </figure>
    </a>

    ---

    <a href="https://learn.sparkfun.com/tutorials/installing-arduino-ide">
      <b>Installing Arduino IDE</b>
    </a>
<!-- ----------WHITE SPACE BETWEEN GRID CARDS---------- -->
-   <a href="https://learn.sparkfun.com/tutorials/redboard-turbo-hookup-guide">
      <figure markdown>
        IoT RedBoard ESP32 Development Board Hookup Guide
      </figure>
    </a>

    ---

    <a href="hhttps://learn.sparkfun.com/tutorials/iot-redboard-esp32-development-board-hookup-guide">
      <b>IoT RedBoard ESP32 Development Board Hookup Guide</b>
    </a>
<!-- ----------WHITE SPACE BETWEEN GRID CARDS---------- -->
-   <a href="https://learn.sparkfun.com/tutorials/installing-board-definitions-in-the-arduino-ide">
      <figure markdown>
        Installing Board Definitions in the Arduino IDE
      </figure>
    </a>

    ---

    <a href="https://learn.sparkfun.com/tutorials/installing-board-definitions-in-the-arduino-ide">
      <b>Installing Board Definitions in the Arduino IDE</b>
    </a>
<!-- ----------WHITE SPACE BETWEEN GRID CARDS---------- -->
-   <a href="https://learn.sparkfun.com/tutorials/logic-levels">
      <figure markdown>
        Logic Levels
      </figure>
    </a>

    ---

    <a href="https://learn.sparkfun.com/tutorials/logic-levels">
      <b>Logic Levels</b>
    </a>
<!-- ----------WHITE SPACE BETWEEN GRID CARDS---------- -->

-   <a href="https://learn.sparkfun.com/tutorials/how-to-power-a-project/all">
      <figure markdown>
        How to Power a Project
      </figure>
    </a>

    ---

    <a href="https://learn.sparkfun.com/tutorials/how-to-power-a-project/all">
      <b>How to Power a Project</b>
    </a>
<!-- ----------WHITE SPACE BETWEEN GRID CARDS---------- -->
</div>

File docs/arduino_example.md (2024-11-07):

!!! arduino
    This example assumes you are using the latest version of the Arduino IDE on your desktop. If this is your first time using Arduino IDE, library, or board add-on, please review the following tutorials.

    - [Installing the Arduino IDE](https://learn.sparkfun.com/tutorials/installing-arduino-ide)
    - [Installing Board Definitions in the Arduino IDE](https://learn.sparkfun.com/tutorials/installing-board-definitions-in-the-arduino-ide)

!!! note
    If you've never connected an CH340 device to your computer before, you may need to install drivers for the USB-to-serial converter. Check out our section on "[How to Install CH340 Drivers](https://learn.sparkfun.com/tutorials/how-to-install-ch340-drivers)" for help with the installation.

    - [How to Install CH340 Drivers](https://learn.sparkfun.com/tutorials/how-to-install-ch340-drivers/all)

For the scope of this tutorial, we will highlight the example from the GitHub repository to get started. Head to the GitHub repository to download the example.  

<div style="text-align: center">
    <a href="https://github.com/sparkfun/SparkFun_Soft_Power_Switch_Mk2" class="md-button md-button--primary">GitHub Repo > SparkFun_Soft_Power_Switch_Mk2</a>
</div>

### Upload Arduino Example

After unzipping the compressed files, navigate to the example: ... > **SparkFun_Soft_Power_Switch_USB-C-main** > **Examples** > **SoftPowerSwitchMk2_Example** > **SoftPowerSwitchMk2_Example**.

If you have not already, connect the Soft Power Switch's power, OFF, and PUSH to your Arduino's GPIO pins.  In this case, we used the SparkFun IoT RedBoard - ESP32 Development Board. Depending on your microcontroller, you may need to adjust the pin connections and definitions with respect to the microcontroller's GPIO pins.  At this point, you can connect the LiPo battery into the Soft Power Switch's IN port and connect the OUT port to the RedBoard's battery input.

<div style="text-align: center;">
    <table>
        <tr>
            <th style="text-align: center; vertical-align: middle; border: solid 1px #cccccc;">Soft Power Switch - JST 2mm
            </th>
            <th style="text-align: center; vertical-align: middle; border: solid 1px #cccccc;">SparkFun IoT RedBoard -<br />ESP32 Development Board
            </th>
        </tr>
        <tr>
            <td style="text-align: center; border: solid 1px #cccccc;" bgcolor="#f2dede"><font color="#000000">VOUT</font>
            </td>
            <td style="text-align: center; border: solid 1px #cccccc;" bgcolor="#f2dede"><font color="#000000">+</font>
            </td>
        </tr>
        <tr>
            <td style="text-align: center; border: solid 1px #cccccc;" bgcolor="#DDDDDD"><font color="#000000">GND</font>
            </td>
            <td style="text-align: center; border: solid 1px #cccccc;" bgcolor="#DDDDDD"><font color="#000000">GND</font>
            </td>
        </tr>
        <tr>
            <td style="text-align: center; border: solid 1px #cccccc;" bgcolor="#cce5ff"><font color="#000000">OFF</font>
            </td>
            <td style="text-align: center; border: solid 1px #cccccc;" bgcolor="#cce5ff"><font color="#000000"><code>32</code> (or <code>A4</code>)</font>
            </td>
        </tr>
        <tr>
            <td style="text-align: center; border: solid 1px #cccccc;" bgcolor="#d4edda"><font color="#000000">PUSH</font>
            </td>
            <td style="text-align: center; border: solid 1px #cccccc;" bgcolor="#d4edda"><font color="#000000"><code>14</code></font>
            </td>
        </tr>
    </table>
</div>

<div style="text-align: center;">
  <table>
    <tr style="vertical-align:middle;">
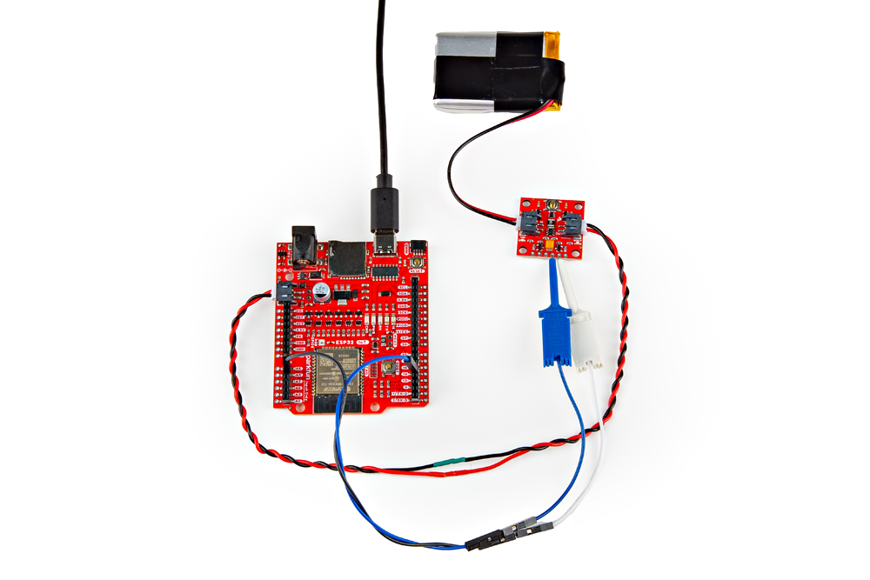
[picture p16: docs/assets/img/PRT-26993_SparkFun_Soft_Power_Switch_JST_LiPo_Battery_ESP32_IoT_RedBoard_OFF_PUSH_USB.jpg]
Uploading Code to ESP32 IoT RedBoard with Soft Power Switch Connected
     <td style="text-align: center; vertical-align: middle; border: solid 1px #cccccc;"></td>
    </tr>
    <tr style="vertical-align:middle;">
     <td style="text-align: center; vertical-align: middle; border: solid 1px #cccccc;"><i>Uploading Code to ESP32 IoT RedBoard with Soft Power Switch Connected</i></td>
    </tr>
  </table>
</div>

For users using an Arduino microcontroller, select your board in the Tools menu (in our case the **SparkFun ESP32 RedBoard IoT RedBoard**) and the correct Port it enumerated on. You can also copy or paste the code as shown below. Then click "Upload".

``` c++
    /*
      Control the power to a system using the SparkFun Soft Power Switch Mk2
      By: Nathan Seidle
      Adapted by: Paul Clark
      SparkFun Electronics
      Date: March 14th, 2024
      License: MIT. See license file for more information

      This example assumes the OFF pin is connected.

      A simple tap of the power button will turn on the system. If the power button is not being pressed
      (accidental tap) the system will turn off after ~20ms. If the system turns on and sees the power
      button held for 0.5s, it will begin normal operation.

      During normal system operation, if user presses the power button for 2s, the system
      will shut down. This means the power button can also be used as a general 'select' button as
      long as user doesn't hold button for more than 2s.

      This example will output serial states. If you are powering your board over a USB connection then
      the power button can't do its job. We did our testing by connecting the TX and GND pins of a RedBoard to
      an external USB to Serial adapter. That way the battery + Soft Power Switch could control power
      to the board.  
    */

    //Hardware connections - GPIO pins (change these as required)
    int _PUSH = 14; // Connect this GPIO to the PUSH breakout pad
    int _OFF = 32; // Connect this GPIO to the OFF breakout pad

    int STAT_LED = LED_BUILTIN;

    unsigned long powerPressedStartTime = 0;

    int debounceDelay = 20;

    //Uncomment the following line to turn on shutdown time measurements
    //#define PRINT_TIMER_OUTPUT

    void setup()
    {
      Serial.begin(115200);
      Serial.println("Soft Power Switch Mk2 example");

      pinMode(_PUSH, INPUT_PULLUP);

      //User has pressed the power button to turn on the system
      //Was it an accidental bump or do they really want to turn on?
      //Let's make sure they continue to press for two seconds
      Serial.print("Initial power on check");
      powerPressedStartTime = millis();
      while (digitalRead(_PUSH) == LOW)
      {
        //Wait for user to stop pressing button.
        //What if user has left something heavy pressing the power button?
        //The soft power switch will automatically turn off the system! Handy.
        delay(100);

        if ((millis() - powerPressedStartTime) > 500)
          break;
        Serial.print(".");
      }
      Serial.println();

      if ((millis() - powerPressedStartTime) < 500)
      {
        Serial.println("Power button tap. Returning to off state. Powering down");
        powerDown();
      }

      Serial.println("User wants to turn system on!");
      powerPressedStartTime = 0; //Reset var to return to normal 'on' state

      //Here we display something to user indicating system is on and running
      //For example an external display or LED turns on
      pinMode(STAT_LED, OUTPUT);
      digitalWrite(STAT_LED, HIGH);

      Serial.println("Press 'r' to enter infinite loop to test power-down override");
      Serial.println("Press 'z' to do a powerdown");
      Serial.println("Press and hold power button for 2s to do a powerdown");

      while (Serial.available()) // Flush the Serial RX buffer
        Serial.read();
    }

    void loop()
    {
      if (Serial.available())
      {
        char incoming = Serial.read();

        if (incoming == 'z')
        {
          Serial.println("Power down");
          powerDown();
        }
        else if (incoming == 'r')
        {
          Serial.println("System locked. Now hold power button to force power down without using software");

          //Here we wait for user press button so we can time it
          while (digitalRead(_PUSH) == HIGH)
            delay(1);

          powerPressedStartTime = millis();
          Serial.println("Doing nothing, waiting for power override to kick in");
          while (1)
          {
    #ifdef PRINT_TIMER_OUTPUT
            Serial.println(millis() - powerPressedStartTime);
    #endif
            delay(1);

            if(digitalRead(_PUSH) == HIGH) break;
          }
          Serial.println("User released button before forced powered could complete. Try again, but hold power button for 7s");
          powerPressedStartTime = 0; //Reset var to return to normal 'on' state
        }
      }

      if (digitalRead(_PUSH) == LOW && powerPressedStartTime == 0)
      {
        //Debounce check
        delay(debounceDelay);
        if (digitalRead(_PUSH) == LOW)
        {
          Serial.println("User is pressing power button. Start timer.");
          powerPressedStartTime = millis();
        }
      }
      else if (digitalRead(_PUSH) == LOW && powerPressedStartTime > 0)
      {
        //Debounce check
        delay(debounceDelay);
        if (digitalRead(_PUSH) == LOW)
        {
          if ((millis() - powerPressedStartTime) > 2000) // Check if button has been held for >= 2 seconds
          {
            Serial.println("Time to power down!");
            powerDown();
          }
        }
      }
      else if (digitalRead(_PUSH) == HIGH && powerPressedStartTime > 0)
      {
        //Debounce check
        delay(debounceDelay);
        if (digitalRead(_PUSH) == HIGH)
        {
          Serial.print("Power button released after ms: ");
          Serial.println(millis() - powerPressedStartTime);
        }
        powerPressedStartTime = 0; //Reset var to return to normal 'on' state
      }
    }

    //Immediately power down
    void powerDown()
    {
      //Indicate to user we are shutting down
      digitalWrite(STAT_LED, LOW);

      Serial.println("Pulling OFF high");
      Serial.flush();

      powerPressedStartTime = millis();

      pinMode(_OFF, OUTPUT);
      digitalWrite(_OFF, HIGH); // Pull OFF high to turn the power off

      while (1)
      {
    #ifdef PRINT_TIMER_OUTPUT
        Serial.println(millis() - powerPressedStartTime);
    #endif
        delay(1);
      }
    }
```

After uploading the code, disconnect the Arduino from your COM port. Then wire a 3.3V Serial Basic Breakout to the Arduino&apos;s serial UART. In this case, we connected to the SparkFun IoT RedBoard - ESP32 Development Board. Depending on your microcontroller, you may need to adjust the pin connections and definitions with respect to the microcontroller's UART pins.

<div style="text-align: center;">
    <table>
        <tr>
            <th style="text-align: center; vertical-align: middle; border: solid 1px #cccccc;">3.3V Serial Basic
            </th>
            <th style="text-align: center; vertical-align: middle; border: solid 1px #cccccc;">SparkFun IoT RedBoard<br />- ESP32 Development Board
            </th>
        </tr>
        <tr>
            <td style="text-align: center; border: solid 1px #cccccc;" bgcolor="#d4edda"><font color="#000000">TXO</font>
            </td>
            <td style="text-align: center; border: solid 1px #cccccc;" bgcolor="#d4edda"><font color="#000000">3/RX-0</font>
            </td>
        </tr>

        <tr>
            <td style="text-align: center; border: solid 1px #cccccc;" bgcolor="#ffdaaf"><font color="#000000">RXI</font>
            </td>
            <td style="text-align: center; border: solid 1px #cccccc;" bgcolor="#ffdaaf"><font color="#000000">1/TX-0</font>
            </td>
        </tr>
        <tr>
            <td style="text-align: center; border: solid 1px #cccccc;" bgcolor="#DDDDDD"><font color="#000000">GND</font>
            </td>
            <td style="text-align: center; border: solid 1px #cccccc;" bgcolor="#DDDDDD"><font color="#000000">GND</font>
            </td>
        </tr>
    </table>
</div>

<div style="text-align: center;">
  <table>
    <tr style="vertical-align:middle;">
     <td style="text-align: center; vertical-align: middle; border: solid 1px #cccccc;"><a href="../assets/img/PRT-26993_SparkFun_Soft_Power_Switch_JST_LiPo_Battery_ESP32_IoT_RedBoard_Serial_Basic_USB.jpg">3.3V Serial Basic Connected to ESP32 IoT RedBoard Hardware</a></td>
    </tr>
    <tr style="vertical-align:middle;">
     <td style="text-align: center; vertical-align: middle; border: solid 1px #cccccc;"><i>3.3V Serial Basic Connected to ESP32 IoT RedBoard Hardware</i></td>
    </tr>
  </table>
</div>

### Initial Boot

Open the [Serial Monitor](https://learn.sparkfun.com/tutorials/terminal-basics) or terminal emulator of your choice, and connect to the 3.3V Serial Basic Breakout&apos;s COM port with the baud rate set to **115200**. Hit the reset button on the ESP32 IoT RedBoard. Since we are using the ESP32, we will see an initial output when the microcontroller boots up. If the button is not held down for 0.5 seconds, you will receive the following message as shown below.

``` bash
Soft Power Switch Mk2 example
Initial power on check
Power button tap. Returning to off state. Powering down
Pulling OFF high
```

<div style="text-align: center;">
  <table>
    <tr style="vertical-align:middle;">
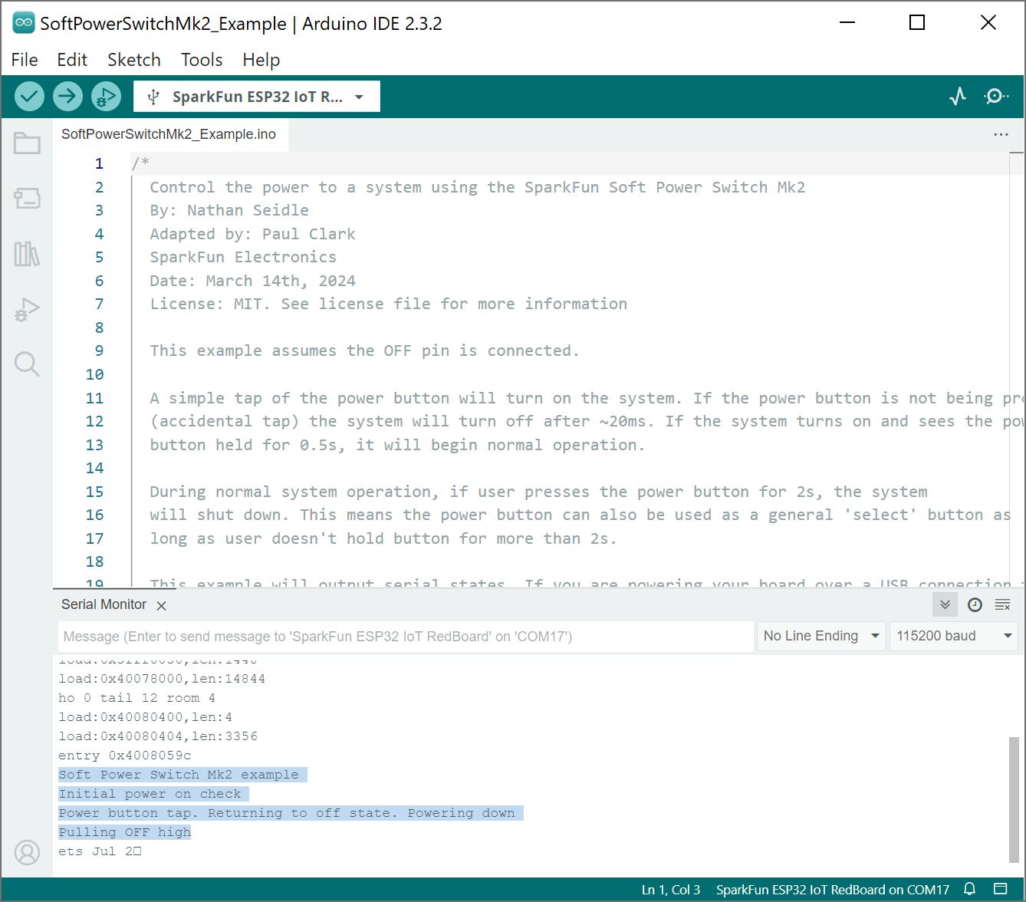
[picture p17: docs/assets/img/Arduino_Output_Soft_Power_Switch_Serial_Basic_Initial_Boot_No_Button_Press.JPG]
Arduino Output Soft Power Switch - JST 2mm with No Button Press on Startup
     <td style="text-align: center; vertical-align: middle; border: solid 1px #cccccc;"></td>
    </tr>
    <tr style="vertical-align:middle;">
     <td style="text-align: center; vertical-align: middle; border: solid 1px #cccccc;"><i>Arduino Output Soft Power Switch - JST 2mm with No Button Press on Startup</i></td>
    </tr>
  </table>
</div>

### Normal Operation - Power On

Press down on the button for just over 0.5 seconds (but no longer than 2 seconds) to power your Arduino for normal system operation. Once the ESP32 boots up, you should see the following output. A timer will begin checking the length of time that the button has been pressed down. Once the button has been released, you will receive an output indicating the amount of time that the button has been pressed down after 0.5 seconds.

```bash
Soft Power Switch Mk2 example
Initial power on check....
User wants to turn system on!
Press 'r' to enter infinite loop to test power-down override
Press 'z' to do a powerdown
Press and hold power button for 2s to do a powerdown
User is pressing power button. Start timer.
Power button released after ms: 300
```

<div style="text-align: center;">
  <table>
    <tr style="vertical-align:middle;">
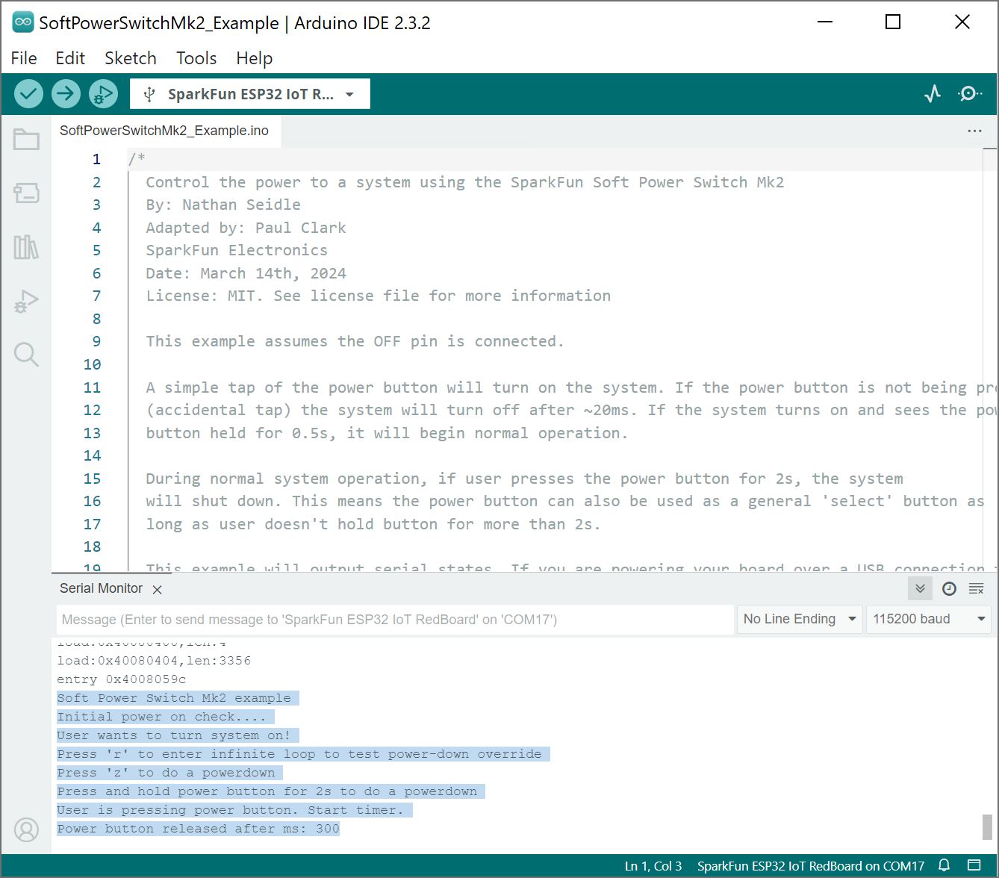
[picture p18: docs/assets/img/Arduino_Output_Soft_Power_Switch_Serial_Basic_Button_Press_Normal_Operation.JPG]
Arduino Output Soft Power Switch - JST 2mm Normal Operation - Power On
     <td style="text-align: center; vertical-align: middle; border: solid 1px #cccccc;"></td>
    </tr>
    <tr style="vertical-align:middle;">
     <td style="text-align: center; vertical-align: middle; border: solid 1px #cccccc;"><i>Arduino Output Soft Power Switch - JST 2mm Normal Operation - Power On</i></td>
    </tr>
  </table>
</div>

!!! note
    The wake-up time can be tweaked to your own user experience. We found 500ms for power up work really well.

### Normal Operation - Power Off

Let's try turning the power off under normal operation. Press the power button for 2 seconds to power down the Arduino. You will receive the following output. You will also notice that the power LEDs on the SparkFun IoT RedBoard - ESP32 turn off indicating that there is no power.

``` bash
User is pressing power button. Start timer.
Time to power down!
Pulling OFF high
```

<div style="text-align: center;">
  <table>
    <tr style="vertical-align:middle;">
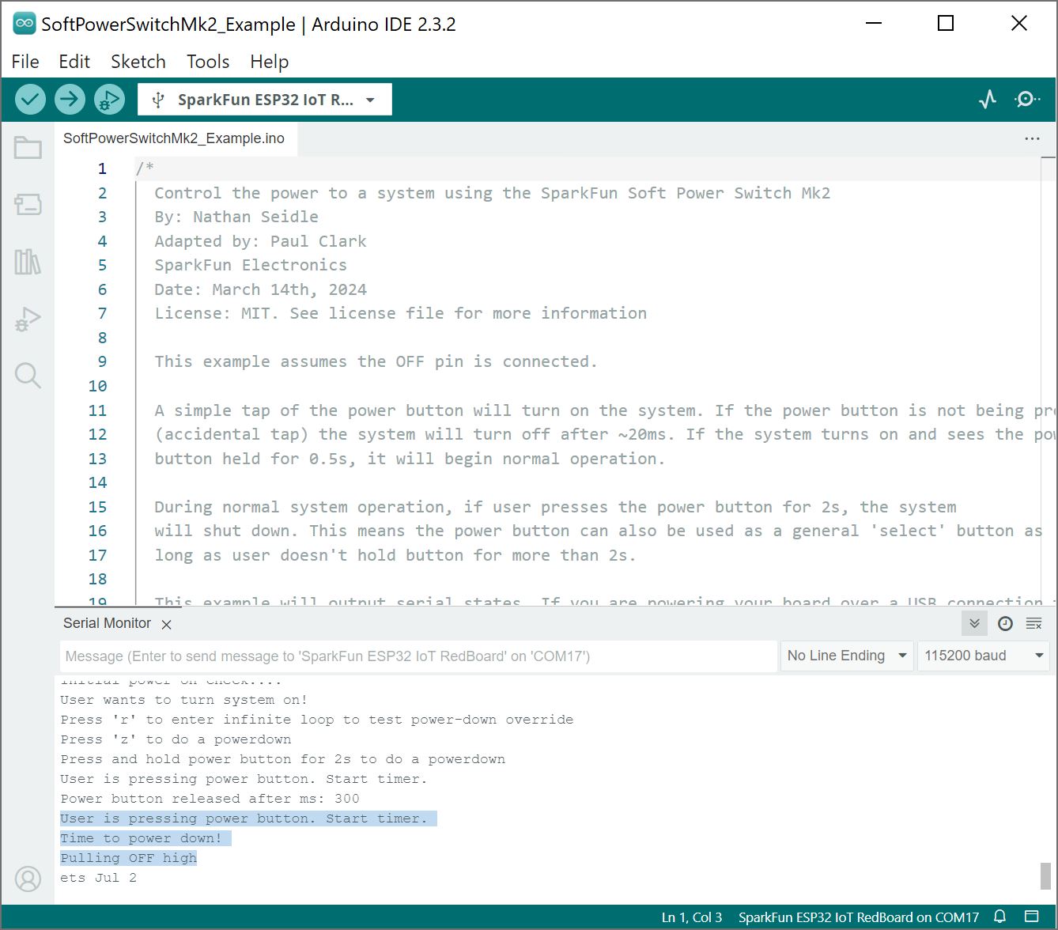
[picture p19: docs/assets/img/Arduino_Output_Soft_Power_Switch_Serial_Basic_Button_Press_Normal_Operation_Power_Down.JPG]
Arduino Output Soft Power Switch - JST 2mm Normal Operation Power Down
     <td style="text-align: center; vertical-align: middle; border: solid 1px #cccccc;"></td>
    </tr>
    <tr style="vertical-align:middle;">
     <td style="text-align: center; vertical-align: middle; border: solid 1px #cccccc;"><i>Arduino Output Soft Power Switch - JST 2mm Normal Operation Power Down</i></td>
    </tr>
  </table>
</div>

!!! note
    The power-down time can be tweaked to your own user experience. We found 2s for power-down work really well. If you decide to adjust the power-down time, make sure to not exceed ~10 seconds as the force power down will take into effect.

### System Lock and Power Down via Arduino Serial Monitor

Remember the output from earlier? There were additional options to control the Soft Power Switch from the Arduino Serial Monitor. Press down on the power button for 0.5 seconds to enter the normal operation again. You will be presented with two options:

* **<kbd>r</kbd>** &mdash; Sending an **r** will cause the Arduino to enter an infinite loop to test power-down override. This will lock the system and force the Soft Power Switch to only shutdown when the button is pressed down rather then sending a character to the Arduino to power down. When locking the system, you will need to press the button down for **7 seconds** to force the Soft Power Switch to power down. Once the button has been pressed down for 7 seconds, the Soft Power Switch will shut power off at the OUT port.
* **<kbd>z</kbd>** &mdash; Sending a **z** will power down the Arduino.

<div style="text-align: center;">
  <table>
    <tr style="vertical-align:middle;">
     <td style="text-align: center; vertical-align: middle; border: solid 1px #cccccc;"><a href="../assets/img/Arduino_Output_Soft_Power_Switch_Serial_Basic_Button_Press_Normal_Operation.JPG">Arduino Output Soft Power Switch - JST 2mm Normal Operation - Power On</a></td>
    </tr>
    <tr style="vertical-align:middle;">
     <td style="text-align: center; vertical-align: middle; border: solid 1px #cccccc;"><i>Arduino Output Soft Power Switch - JST 2mm Normal Operation - Power On</i></td>
    </tr>
  </table>
</div>

Let's send an <kbd>r</kbd> to lock the system to force the Soft Power Switch to power down. Then press down on the power button for 7 seconds. You will receive the following message indicating that the system is locked. Once the power button is pressed down, an additional message on the next line will be output to indicate that we are waiting for the power override. After 7 seconds, power will be disabled at the OUT port and the IoT RedBoard - ESP32 will turn off.

``` bash
System locked. Now hold power button to force power down without using software
Doing nothing, waiting for power override to kick in
```

<div style="text-align: center;">
  <table>
    <tr style="vertical-align:middle;">
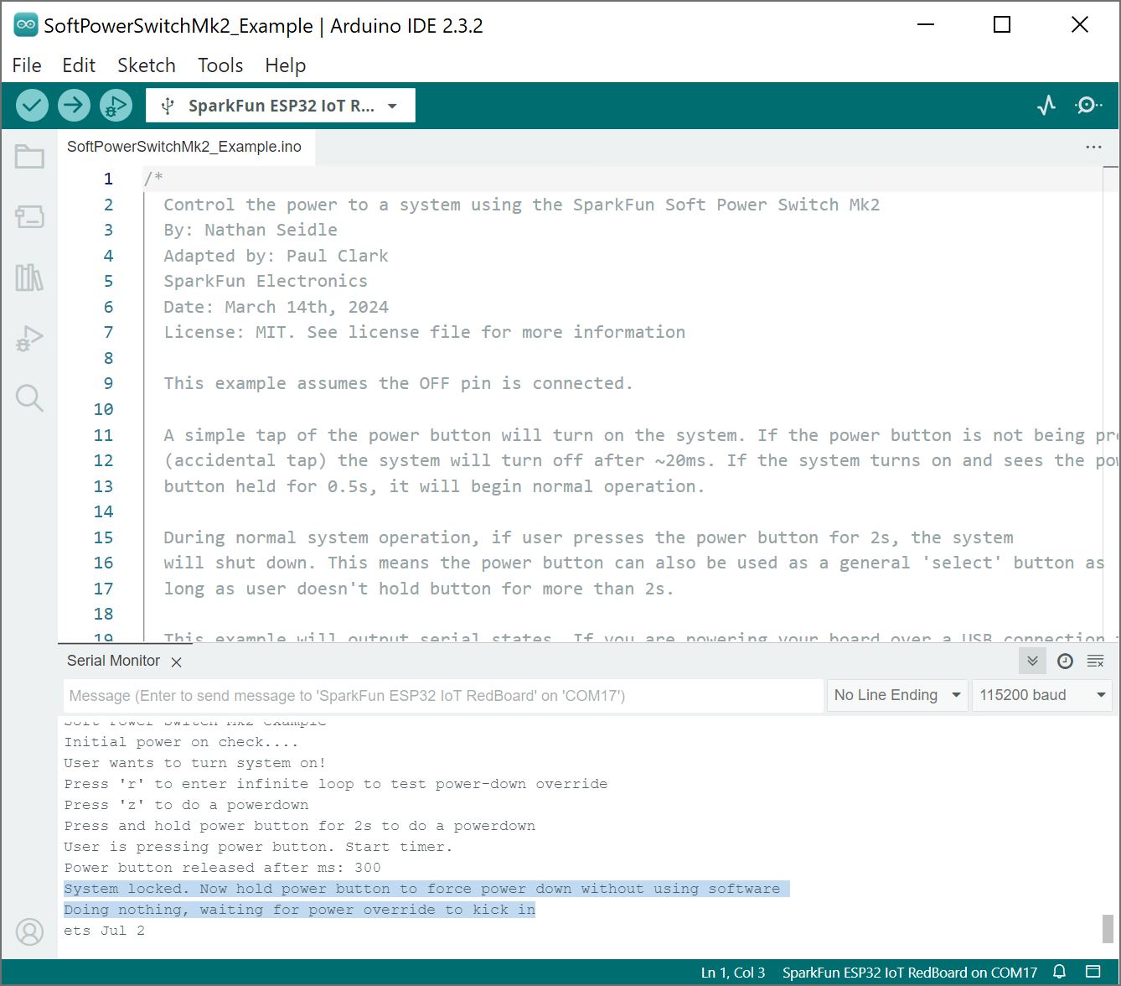
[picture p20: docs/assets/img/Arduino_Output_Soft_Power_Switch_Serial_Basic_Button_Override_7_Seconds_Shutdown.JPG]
Arduino Output Soft Power Switch - JST 2mm Button Override
     <td style="text-align: center; vertical-align: middle; border: solid 1px #cccccc;"></td>
    </tr>
    <tr style="vertical-align:middle;">
     <td style="text-align: center; vertical-align: middle; border: solid 1px #cccccc;"><i>Arduino Output Soft Power Switch - JST 2mm Button Override</i></td>
    </tr>
  </table>
</div>

!!! note
    If the button is released before 7 seconds, you will receive the following message indicating that the forced power down could not be completed when the system is locked. This will break out of the infinite loop and require you to send another <kbd>r</kbd> through the serial terminal in order to test the power-down override again.

    ``` bash
    User released button before forced powered could complete. Try again, but hold power button for 7s
    ```

    <div style="text-align: center;">
      <table>
        <tr style="vertical-align:middle;">
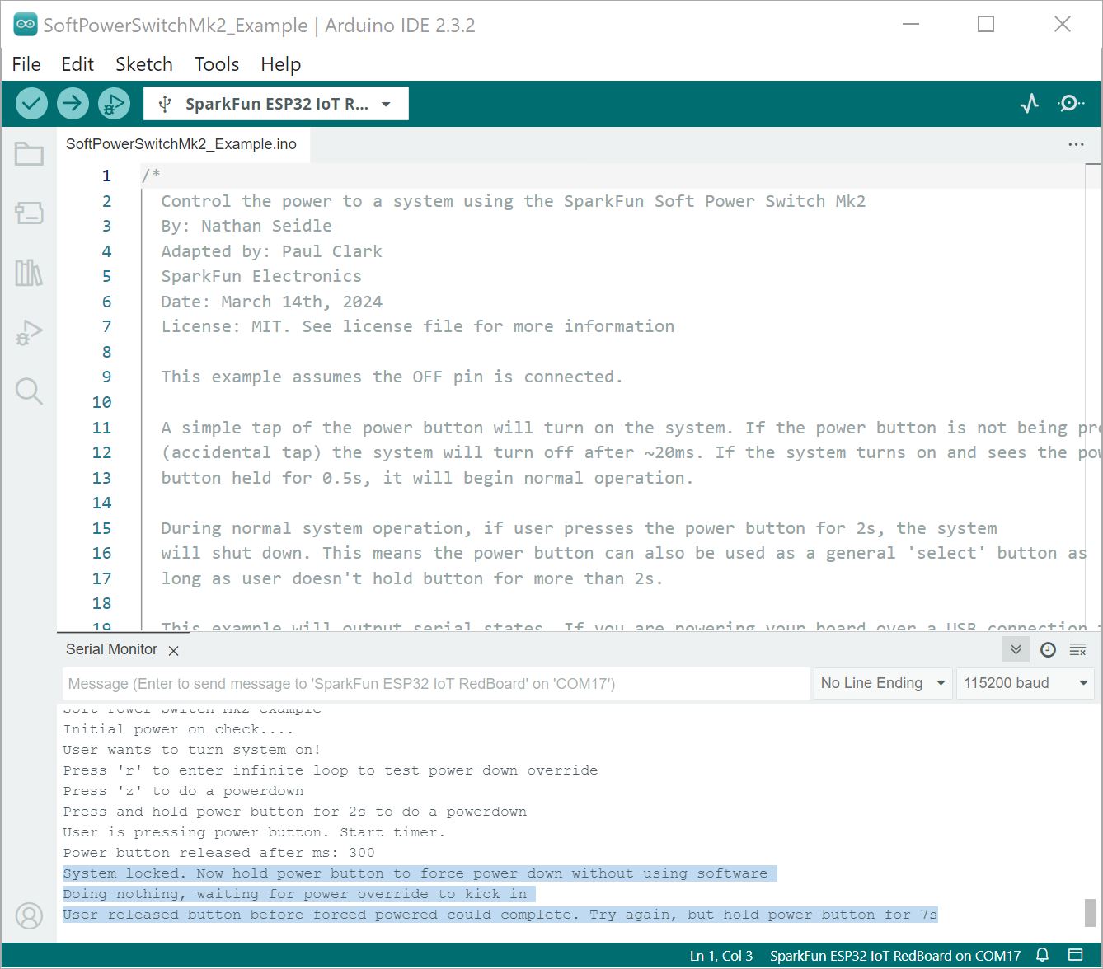
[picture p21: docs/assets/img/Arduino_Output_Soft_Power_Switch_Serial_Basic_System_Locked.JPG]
Arduino Output Soft Power Switch - JST 2mm Unable to Force Power Down
         <td style="text-align: center; vertical-align: middle; border: solid 1px #cccccc;"></td>
        </tr>
        <tr style="vertical-align:middle;">
         <td style="text-align: center; vertical-align: middle; border: solid 1px #cccccc;"><i>Arduino Output Soft Power Switch - JST 2mm Unable to Force Power Down</i></td>
        </tr>
      </table>
    </div>

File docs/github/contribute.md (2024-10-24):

# Contribute: Help Fix our Mistake!
Spot something wrong? Feel free to contribute our open-source design and documentation. 

## Improve our Documentation
All of this documentation can be modified by you! Please help us make it better.

* These pages are contained in the [`docs` folder of the SparkFun Soft Power Switch Mk2 repository](https://github.com/sparkfun/SparkFun_Soft_Power_Switch_Mk2/tree/main/docs).

### Submit a Correction
1. Fork this repo
2. Add your corrections or improvements to the markdown file
3. File a pull request with your changes, and enjoy making the ~~words~~ ~~worlds~~ world a better place.
    * Once received, the documentation specialist will automatically be notified.
    * We will review your suggested improvements to make sure they are correct and fit within our documentation standards.

## Improve our Hardware Design
All of our designs are open-source! Please help us make it better.

* Our board design files are contained in the [`Hardware` folder of the SparkFun Soft Power Switch Mk2 repository](https://github.com/sparkfun/SparkFun_Soft_Power_Switch_Mk2/tree/main/Hardware).

### Submit a Design Improvement
1. Fork this repo
2. Add your design improvements
3. File a pull request with your changes, and enjoy making the ~~words~~ ~~worlds~~ world a better place.
    * Once received, the engineer in charge of the original design will automatically be notified.
    * We will review your suggested improvements, if they are within our board design standards and meet our product design requirements, we will flag these changes for our next board revision. *(Please note, that even if your suggestion is accepted, these changes may not be immediate. We may have to cycle through our current product inventory first.)*

## Contributors
Let's provided some recognition to the contributors for this project!

GitHub Contributors Image
<br>


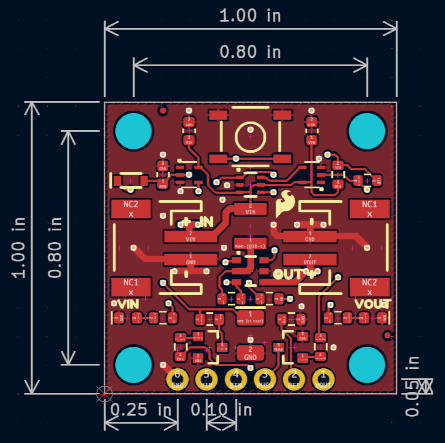
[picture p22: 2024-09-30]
Hardware/Dimensions.png

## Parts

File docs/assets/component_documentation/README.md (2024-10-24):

SparkFun Documentation
=======================

This directory should include any necessary datasheets, example number crunching, etc.

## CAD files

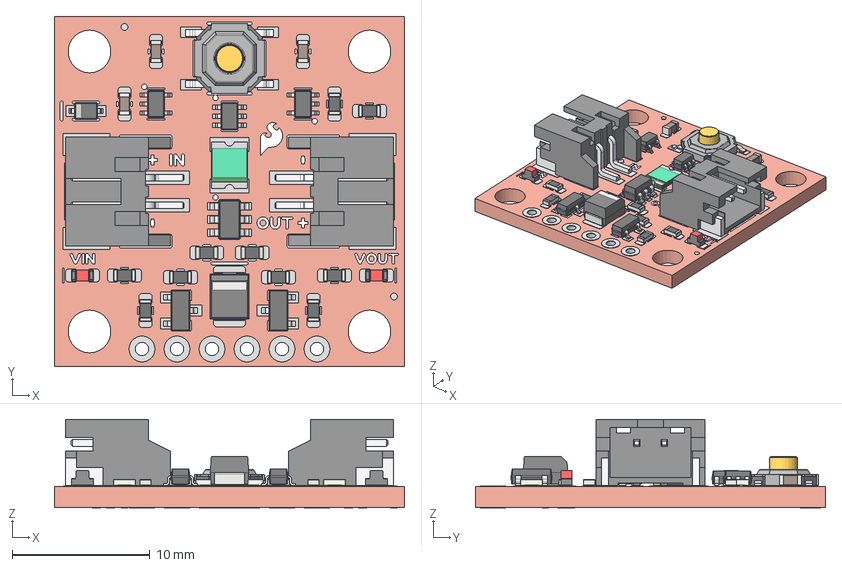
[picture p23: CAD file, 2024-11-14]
docs/assets/3d_model/Soft_Power_Switch_JST_2mm_3D_Model.step
25.4 x 25.4 x 6.47 mm
SOT-23-6
SOT-353_SC-70-5 x 2
R_0603_1608Metric x 10
LED_0603_1608Metric_Red x 2
SOT-23 x 2
JST-PH-2 v1 x 10
C_0603_1608Metric x 3
SOT-363_SC-70-6
D_SOD-323
59EABDD3-378C-4408-8BAB-872EA4CE998E x 7
CP_EIA-3528-21_Vishay-B
Fuse_1210_3225Metric
Soft_Power_Switch_copper
Soft_Power_Switch_pad
Soft_Power_Switch_silkscreen
Soft_Power_Switch_PCB

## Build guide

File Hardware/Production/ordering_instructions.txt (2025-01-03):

Ordering Instructions:
Panel dimensions: 142.70 x 194.50 mm.
Solder Mask: Red
Silkscreen Color: White
Layers: 2
Finish: HASL
Thickness: 1.6mm
Copper Weight: 1oz
Minimum track width: 0.18mm (7.00mil)
Minimum via drill: 0.30mm (11.81mil)

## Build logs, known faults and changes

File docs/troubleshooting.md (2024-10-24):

### General Troubleshooting Help

!!! note
    <span class="glyphicon glyphicon-question-sign" aria-hidden="true"></span>
        <strong> Not working as expected and need help? </strong> <br /><br />

    If you need technical assistance and more information on a product that is not working as you expected, we recommend heading on over to the <a href="https://www.sparkfun.com/technical_assistance">SparkFun Technical Assistance</a> page for some initial troubleshooting. <br /><br />

    <div style="text-align: center"><a href="https://www.sparkfun.com/technical_assistance" target="sfe_technical_assistance" class="md-button">SparkFun Technical Assistance Page</a></div>

    If you don't find what you need there, the <a href="https://community.sparkfun.com/">SparkFun Forums</a> are a great place to find and ask for help. If this is your first visit, you'll need to create a forum account to search product forums and post questions.<br /><br />

    <div style="text-align: center"><a href="https://community.sparkfun.com/" class="md-button md-button--primary">Log Into SparkFun Forums</a></div>

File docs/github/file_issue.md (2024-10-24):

# Did we make a mistake?

Spot something wrong? Please let us know. 

!!! attention
    This is not where customers should seek assistance on a product. If you require technical assistance or have questions about a product that is not working as expected, please head over to the [SparkFun Technical Assistance](https://www.sparkfun.com/technical_assistance) page for some initial troubleshooting.
    <center>
    [SparkFun Technical Assistance Page](https://www.sparkfun.com/technical_assistance){ .md-button .md-button--primary }
    </center>

    If you can't find what you need there, you'll need a [Forum Account](https://forum.sparkfun.com/ucp.php?mode=register) to search product forums and post questions.

## Discrepancies in the Documentation

All of this documentation can be modified by you! Please help us make it better.

* The documentation files for these pages are contained in the [`docs` folder of the SparkFun Soft Power Switch Mk2 repository](https://github.com/sparkfun/SparkFun_Soft_Power_Switch_Mk2/tree/main/docs).

### Spot something wrong?
If a section of the documentation is incorrect, please [open an issue](https://github.com/sparkfun/SparkFun_Soft_Power_Switch_Mk2/issues) and let us know.

### Do you have a suggested correction?
1. With a GitHub account, fork this repo
2. Add your correction(s) or improvement(s) to the markdown file(s)
3. File a pull request with your changes, and enjoy making the ~~words~~ ~~worlds~~ world a better place.
    * Once received, the documentation specialist will automatically be notified.
    * We will review your suggested improvement(s) to make sure they are correct and fit within our documentation standards.

## Problems in the Hardware Design

All of our designs are open-source! Please help us make it better.

* Our board design files are contained in the [`Hardware` folder of the SparkFun Soft Power Switch Mk2 repository](https://github.com/sparkfun/SparkFun_Soft_Power_Switch_Mk2/tree/main/Hardware).

### Does something not make sense?
If part of the design is confusing, please [open an issue](https://github.com/sparkfun/SparkFun_Soft_Power_Switch_Mk2/issues) and let us know.

### Did we forget to include an important function of the board?
* Please keep in mind that we may intentionally exclude certain functions of the board to meet our product design requirements. *(For example, our Qwiic Micro boards are intended to fit on a small board layout and only use I<sup>2</sup>C communication; therefore, we may not have the SPI and interrupt pins available for users.)*
* If part of the board's functionality is missing, please [open an issue](https://github.com/sparkfun/SparkFun_Soft_Power_Switch_Mk2/issues) and file a feature request.

### Do you wish to contribute directly to improving the board design?
1. With a GitHub account, Fork this repo
2. Add your design improvement(s)
3. File a pull request with your changes, and enjoy making the ~~words~~ ~~worlds~~ world a better place.
    * Once received, the engineer in charge of the original design will automatically be notified.
    * We will review your suggested improvement(s), if they are within our board design standards and meet our product design requirements, we will flag these changes for our next board revision. *(Please note, that even if your suggestion is accepted, these changes may not be immediate. We may have to cycle through our current product inventory first.)*

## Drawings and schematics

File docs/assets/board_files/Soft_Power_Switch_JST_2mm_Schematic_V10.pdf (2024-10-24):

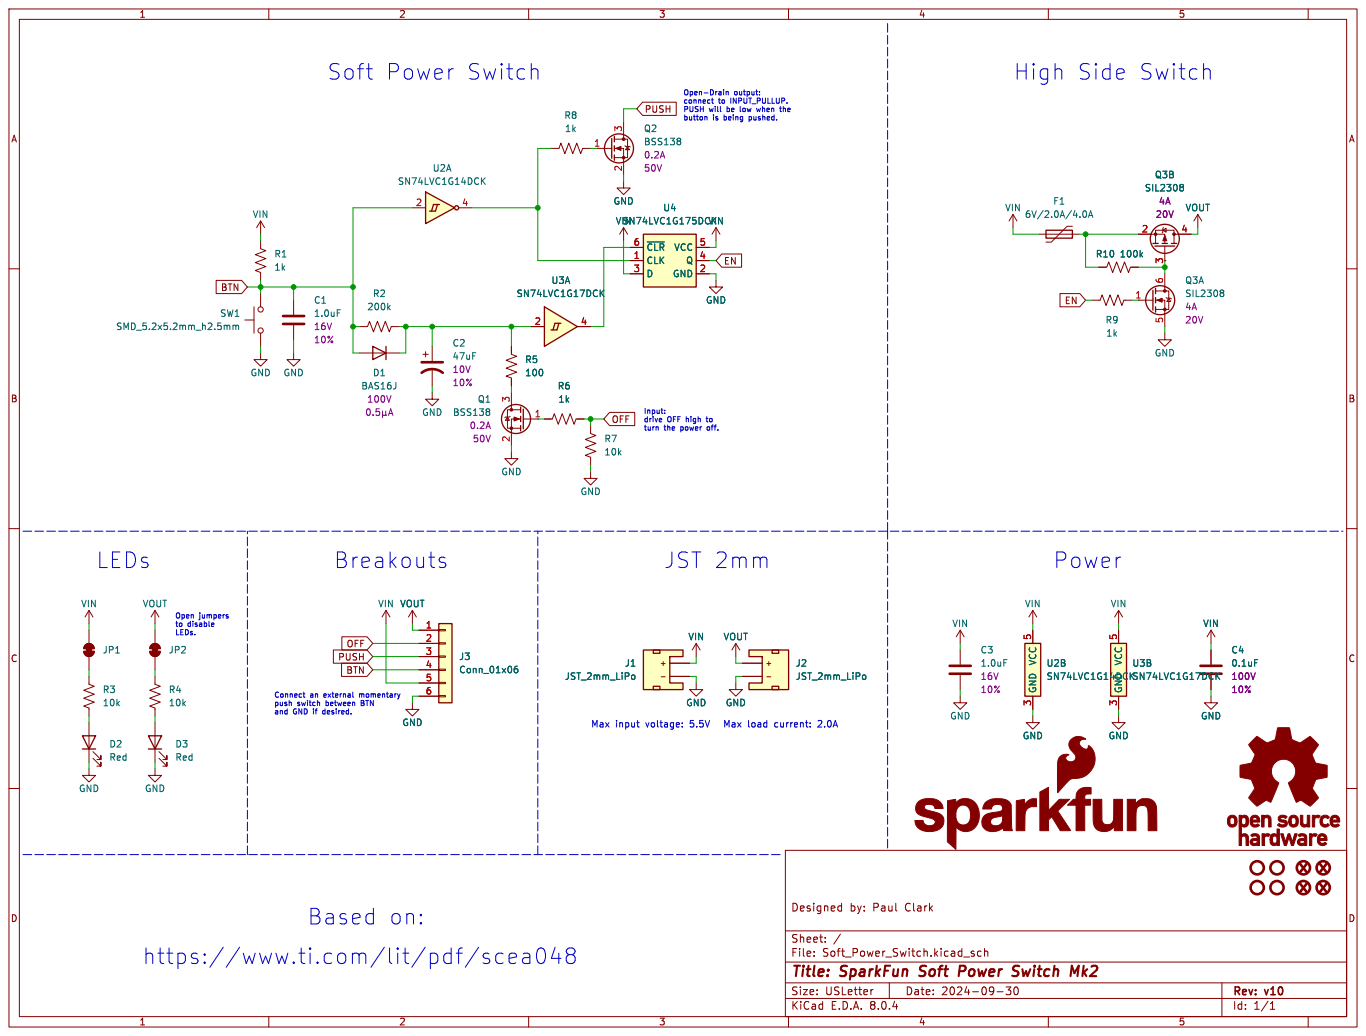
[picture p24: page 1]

button is being pushed. Open jumpers

Input: drive OFF high to

turn the power off. Breakouts

and GND if desired. https://www.ti.com/lit/pdf/scea048

Id: 1/1 Title: SparkFun Soft Power Switch Mk2

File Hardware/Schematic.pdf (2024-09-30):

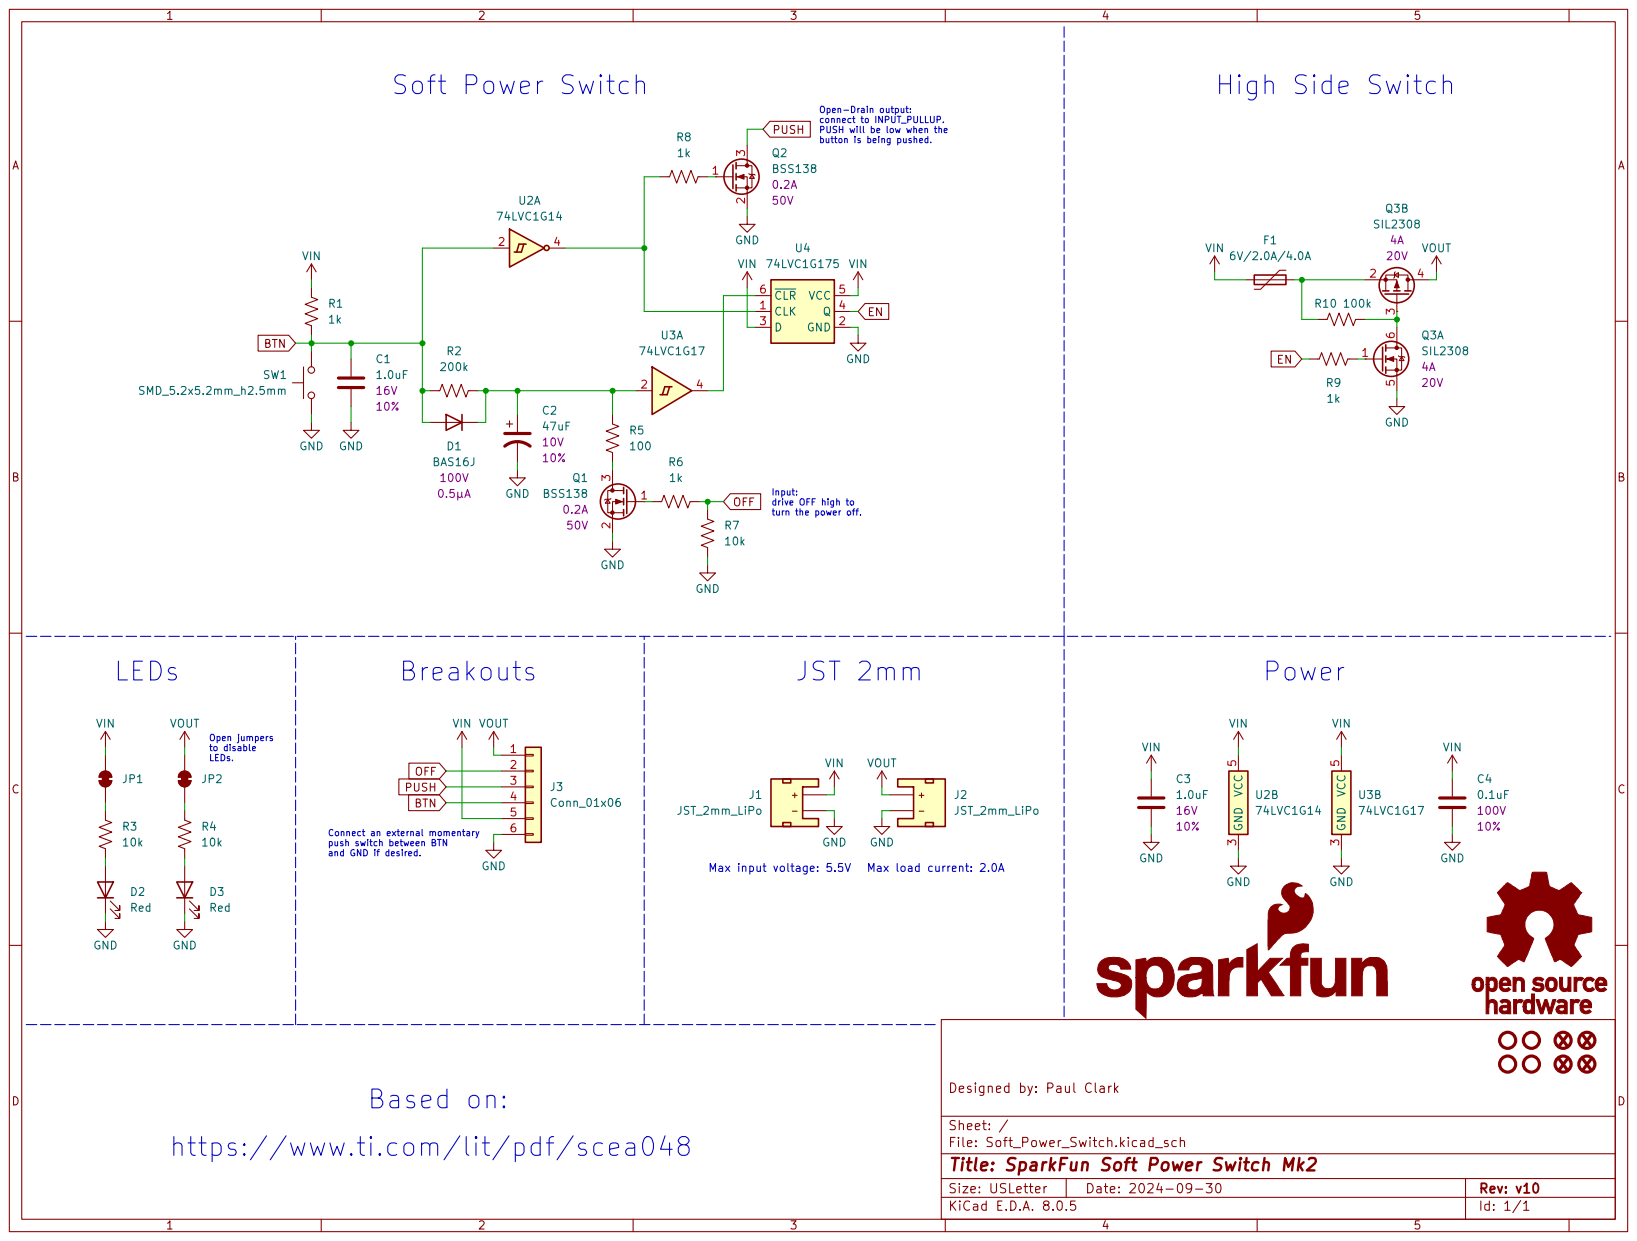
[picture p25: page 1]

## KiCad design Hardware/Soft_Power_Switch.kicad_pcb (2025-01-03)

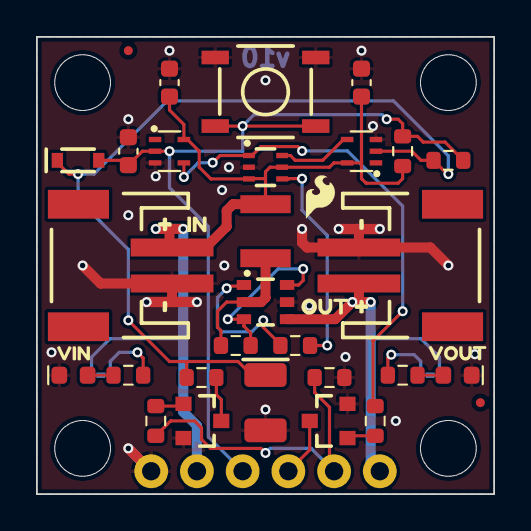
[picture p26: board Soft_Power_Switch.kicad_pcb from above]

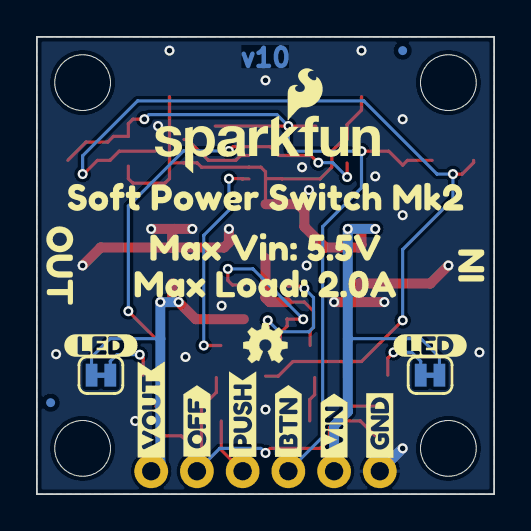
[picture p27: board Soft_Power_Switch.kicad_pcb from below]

Board: 2 copper layers, 25.4 x 25.4 mm, 61 parts (18 on the bottom side), 20 nets.

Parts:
C1, C3: 1.0uF; C_0603_1608Metric
C2: 47uF; EIA-3528
C4: 0.1uF; C_0603_1608Metric
D1: BAS16J; SOD-323
D2, D3: Red; LED_0603_1608Metric_Red
F1: 6V/2.0A/4.0A; 1210
FID1, FID2, FID3, FID4: Fiducial_0.5mm; Fiducial_0.5mm_Mask1mm
G3: OSHW_Logo; Creative_Commons_License
J1, J2: JST_2mm_LiPo; JST_SMD_2.0mm-2
J3: Conn_01x06; 1x06
JP1, JP2: Jumper_2_NC_Trace
Q1, Q2: BSS138; SOT23-3
Q3: SIL2308; SOT23-6-Tight
R1, R6, R8, R9: 1k; R_0603_1608Metric
R2: 200k; R_0603_1608Metric
R3, R4, R7: 10k; R_0603_1608Metric
R5: 100; R_0603_1608Metric
R10: 100k; R_0603_1608Metric
Ref**: Val**; OSHW_Logo_2.5mm
ST1, ST2, ST3, ST4: Standoff
SW1: SMD_5.2x5.2mm_h2.5mm; Push_SMD_5.2x5.2mm_h2.5mm
U2: SN74LVC1G14DCK; SOT-353
U3: SN74LVC1G17DCK; SOT-353
U4: SN74LVC1G175DCK; SOT-323
kibuzzard-65F04F60, kibuzzard-65F04F60#2: G***; kibuzzard-65F04F60
kibuzzard-65F04FCA, kibuzzard-65F04FCA#2: G***; kibuzzard-65F04FCA
kibuzzard-65F053F1: G***; kibuzzard-65F053F1
kibuzzard-65F054C3, kibuzzard-65F054C3#2: G***; kibuzzard-65F054C3
kibuzzard-65F056B4: G***; kibuzzard-65F056B4
kibuzzard-65F056D8: G***; kibuzzard-65F056D8
kibuzzard-65F056F7: G***; kibuzzard-65F056F7
kibuzzard-65F174FD: G***; kibuzzard-65F174FD
kibuzzard-65F0543A: G***; kibuzzard-65F0543A
kibuzzard-65F0634B: G***; kibuzzard-65F0634B
kibuzzard-65F0636B: G***; kibuzzard-65F0636B
kibuzzard-65F1758C: G***; kibuzzard-65F1758C
kibuzzard-65F05416: G***; kibuzzard-65F05416
kibuzzard-65F05472: G***; kibuzzard-65F05472
kibuzzard-65F05495: G***; kibuzzard-65F05495
kibuzzard-65F05604: G***; kibuzzard-65F05604
kibuzzard-65F05628: G***; kibuzzard-65F05628
kibuzzard-65F05644: G***; kibuzzard-65F05644

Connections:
BTN: C1.1, D1.A, J3.4, R1.2, R2.2, SW1.2, U2.2
EN: R9.2, U4.4 (Q)
GND: C1.2, C2.2, C3.2, C4.2, D2.1 (K), D3.1 (K), J1.1 (-), J2.1 (-), J3.6, Q1.2 (S), Q2.2 (S), Q3.5 (S), R7.2, SW1.1, U2.3 (GND), U3.3 (GND), U4.2 (GND)
unnamed: C2.1, D1.C, R2.1, R5.1, U3.2
unnamed: D2.2 (A), R3.2
unnamed: D3.2 (A), R4.2
unnamed: JP1.1 (A), R3.1
unnamed: JP2.1 (A), R4.1
unnamed: Q1.3 (D), R5.2
unnamed: Q1.1 (G), R6.1
unnamed: Q2.1 (G), R8.2
unnamed: Q3.3 (G), Q3.6 (D), R10.1
unnamed: Q3.1 (G), R9.1
unnamed: F1.1, Q3.2 (1), R10.2
unnamed: R8.1, U2.4, U4.1 (CLK)
unnamed: U3.4, U4.6 (~CLR)
OFF: J3.2, R6.2, R7.1
PUSH: J3.3, Q2.3 (D)
VIN: C3.1, C4.1, F1.2, J1.2 (+), J3.5, JP1.2 (B), R1.1, U2.5 (VCC), U3.5 (VCC), U4.3 (D), U4.5 (VCC)
VOUT: J2.2 (+), J3.1, JP2.2 (B), Q3.4 (D)

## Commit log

2024-10-01 Update 3D models
    [Soft_Power_Switch.kicad_pcb]
2024-11-07 Adjust Required Materials
2024-11-14 Add 3D Models
    [Soft_Power_Switch_JST_2mm_3D_Model.step]
2024-11-15 Remove STL File
2025-01-03 Add panel. Single PCB gerbers moved into Production_Single_PCB
    [Soft_Power_Switch.GBL, Soft_Power_Switch.GBO, Soft_Power_Switch.GBP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]

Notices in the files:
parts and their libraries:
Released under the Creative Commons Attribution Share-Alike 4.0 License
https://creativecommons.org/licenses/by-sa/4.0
